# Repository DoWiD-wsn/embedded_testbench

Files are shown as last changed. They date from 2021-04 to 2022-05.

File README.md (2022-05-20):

# Embedded Testbench (ETB)

The **E**mbedded **T**est**b**ench (**ETB**) is a platform consisting of a Raspberry Pi add-on and a Python library designed to enable the testing, analyzing, and profiling of embedded systems.
A focus is laid on low-power embedded systems such as wireless sensor nodes.
Additionally, the ETB supports test automation with the possibility of remote control via TCP/IP.

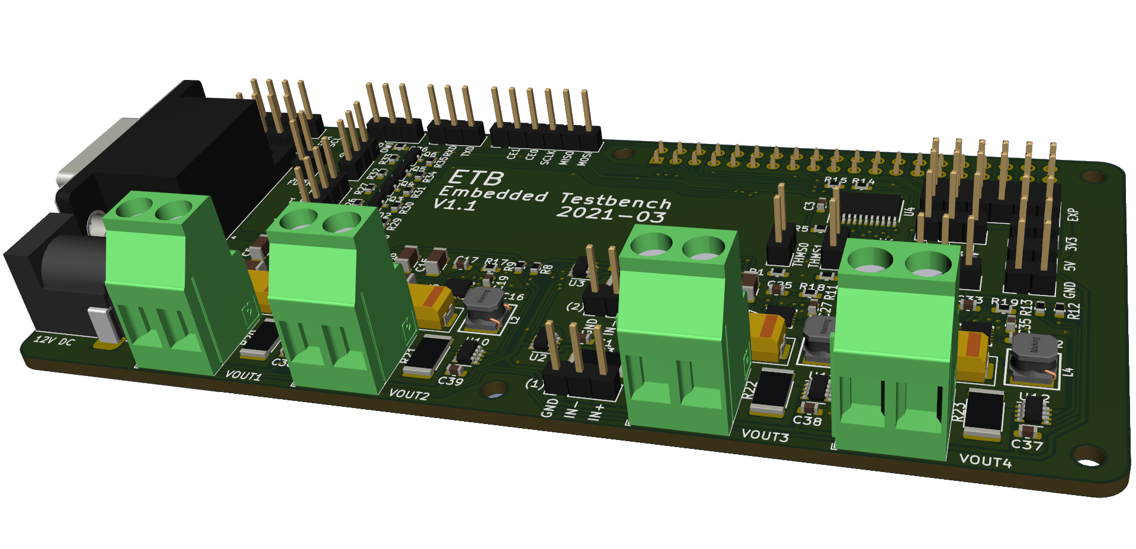
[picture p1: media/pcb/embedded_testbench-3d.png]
PCB 3D (/media/pcb/embedded_testbench-3d.png)


## Key Facts

* 40-pin expansion header for Raspberry Pi [2|3|4] model B+
* 4 mounting holes matching the Raspberry Pi [2|3|4] model B+ layout
* Compact size of 122 x 56 mm
* 4 controllable voltage domains supplied via own 12V input  
    (0.64 to 5.25V, in 5|10|30|50 mV steps, with a current limit of 3A each; see [MIC24045 datasheet](docs/datasheets/mic24045.pdf))
* 6 wattmeter: one per voltage domain + 2 additional  
    (0 to 26V, +/- 3.2A (max), 1.5 mA resolution, 1% precision; see [INA219 datasheet](docs/datasheets/ina219.pdf))
* 4 channel 16-bit ADC: 2 general + 2 for thermistor (see [ADS1115 datasheet](docs/datasheets/ads1115.pdf))
* I2C multiplexer for easier channel selection (voltage supply + wattmeter; see [TCA9548A datasheet](docs/datasheets/tca9548a.pdf))
* 12-pin expansion header (2x PWM, 6x GPIO, +3V3/+5V, and 2x GND)
* 4 test control signals (reset, enable, running, result)
* Connectors for TWI (2x), OWI (1x), SPI (1x), and UART (1x)
* Connectors for UART (1x) and test control signals (1x)  
    (with MOSFET-based bi-directional level shifter for voltage domain #1)
* Connectors for +3V3, +5V, and GND 
* Dsub 15 HD connector for DUT (e.g., useful for climate chamber experiments)

## Contents

```
.
├── docs                : documents & project documentation
│   └── datasheets      : datasheets of components used
├── kicad               : KiCad files
├── media               : Miscellaneous media (images, etc.)
│   ├── pcb             : Photos and rendered images of the PCB
│   └── schematic       : SVG images of the schematics
└── source              : Python library and example scripts
```

For more information on the PCB (and its design) refer to [docs/pcb_design.md](docs/pcb_design.md).
The python library, its functionality, and usage as well as example scripts are presented in [docs/python_library.md](docs/python_library.md).

## Built with

* [KiCad EAD 5.1.9](https://kicad.org/) - PCB design
* [Python 3.7.3](https://www.python.org/) - Python library

## Contributors

* **Dominik Widhalm** - [***DC-RES***](https://informatics.tuwien.ac.at/doctoral/resilient-embedded-systems/) - [*UAS Technikum Wien*](https://embsys.technikum-wien.at/staff/widhalm/)

Contributions of any kind to improve the project are highly welcome.
For coding bugs or minor improvements simply use pull requests.
However, for major changes or general discussions please contact [Dominik Widhalm](mailto:widhalm@technikum-wien.at?subject=Embedded%20Testbench%20(ETB)%20on%20GitHub).

## Publications

The embedded testbench (ETB) has already been successfully utilized in the following publications:

- Dominik Widhalm, Karl M. Goeschka, and Wolfgang Kastner, "*An open-source wireless sensor node platform with active node-level reliability for monitoring applications*", Sensors 21, no. 22: 7613, 2021, DOI: [10.3390/s21227613](https://doi.org/10.3390/s21227613)
- Dominik Widhalm, Karl M. Goeschka, and Wolfgang Kastner, "*Undervolting on wireless sensor nodes: a critical perspective*", in The 23rd International Conference on Distributed Computing and Networking (ICDCN 2022), January 4-7, 2022, DOI: [10.1145/3491003.3491018](https://doi.org/10.1145/3491003.3491018)
- Dominik Widhalm, Karl M. Goeschka, and Wolfgang Kastner, "*Is Arduino a suitable platform for sensor nodes?*", in The 47th Annual Conference of the IEEE Industrial Electronics Society (IECON 2021), October 13-16, 2021, DOI: [10.1109/IECON48115.2021.9589479](https://doi.org/10.1109/IECON48115.2021.9589479)
- Dominik Widhalm, Karl M. Goeschka, and Wolfgang Kastner, "*Node-level indicators of soft faults in wireless sensor networks*", in The 40th International Symposium on Reliable Distributed Systems (SRDS 2021), September 20-23, 2021, DOI: [10.1109/SRDS53918.2021.00011](https://doi.org/10.1109/SRDS53918.2021.00011)

## Changelog

A list of prior versions and changes between the updates can be found inn the [CHANGELOG.md](CHANGELOG.md) file.
Note that the major and minor number refer to the hardware version of the ETB board while the patch version is used to denote subsequent software versions.

## License

This project is licensed under the MIT License - see the [LICENSE.md](LICENSE.md) file for details.

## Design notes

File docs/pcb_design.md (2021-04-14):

# ETB - PCB Design

The board was designed with KiCad `version 5.1.9` and mainly uses schematic symbols and PCB footprints available in the [KiCad libraries](https://kicad.org/libraries/download/).
Parts not included in these libraries are available as project-specific libraries (see below).
The design requires only a two-layer PCB with all components (except the Raspberry Pi header) placed on the top side.
Also, it has enough ground zone area to avoid heating or EMI issues.

## Contents

```
kicad/
├── components                      : hierarchical schematic components
│   ├── ina219.sch                  : INA219-based wattmeter
│   ├── mic24045.sch                : MIC24045-based DC/DC converter
│   ├── shifter_2.sch               : MOSFET-based bi-directional level shifter (2 channel)
│   └── shifter_4.sch               : MOSFET-based bi-directional level shifter (4 channel)
├── myfootprint.pretty              : custom PCB footprints
│   ├── FQFN33-20LD-PL-1.kicad_mod  : FQFN33 footprint for MIC24045
│   └── L_Bourns-SRN5040.kicad_mod  : Bourns SRN5040 inductor footprint
├── embedded_testbench.kicad_pcb    : PCB layout file
├── embedded_testbench.lib          : schematic symbols library file
├── embedded_testbench.ods          : BOM (created with LibreOffice Calc version 7.1.1.2)
├── embedded_testbench.pro          : KiCad project file
├── embedded_testbench.sch          : schematic layout file
├── fp-lib-table                    : project-specific footprint library list
├── mycomponents.dcm                : custom schematic library (descriptions, aliases and keywords)
├── mycomponents.lib                : custom schematic library
└── sym-lib-table                   : project-specific symbol library list
```

## Costs

For the bill of materials (BOM) provided in the `.ods` file links to suitable components available at [Farnell](https://www.farnell.com/) are given including the prices valid at the time of the development (2021-03).
The cost of one *ETB* was around 53€ for the components ([Farnell](https://www.farnell.com/)) and around 15€ for the PCB ([PCB Pool / Beta Layout](https://eu.beta-layout.com/pcb/)).
Thus, the total costs of one *ETB* are below **70€**.
Depending on the supplier and quantities ordered, the costs may vary.

## Schematic

**Main schematic**:  
Main Schematic (/media/schematic/embedded_testbench-main.svg)

**Embedded hierarchical schematics**:  
* MIC24045 Schematic ([#1](../media/schematic/embedded_testbench-mic1.svg),[#2](../media/schematic/embedded_testbench-mic2.svg),[#3](../media/schematic/embedded_testbench-mic3.svg),[#4](../media/schematic/embedded_testbench-mic4.svg))  
* INA219 Schematic ([#1](../media/schematic/embedded_testbench-ina1.svg),[#2](../media/schematic/embedded_testbench-ina2.svg),[#3](../media/schematic/embedded_testbench-ina3.svg),[#4](../media/schematic/embedded_testbench-ina4.svg))  
* [CTRL shifter Schematic](../media/schematic/embedded_testbench-shifter_ctrl.svg)  
* [UART shifter Schematic](../media/schematic/embedded_testbench-shifter_uart.svg)  

## PCB Design

Front:  
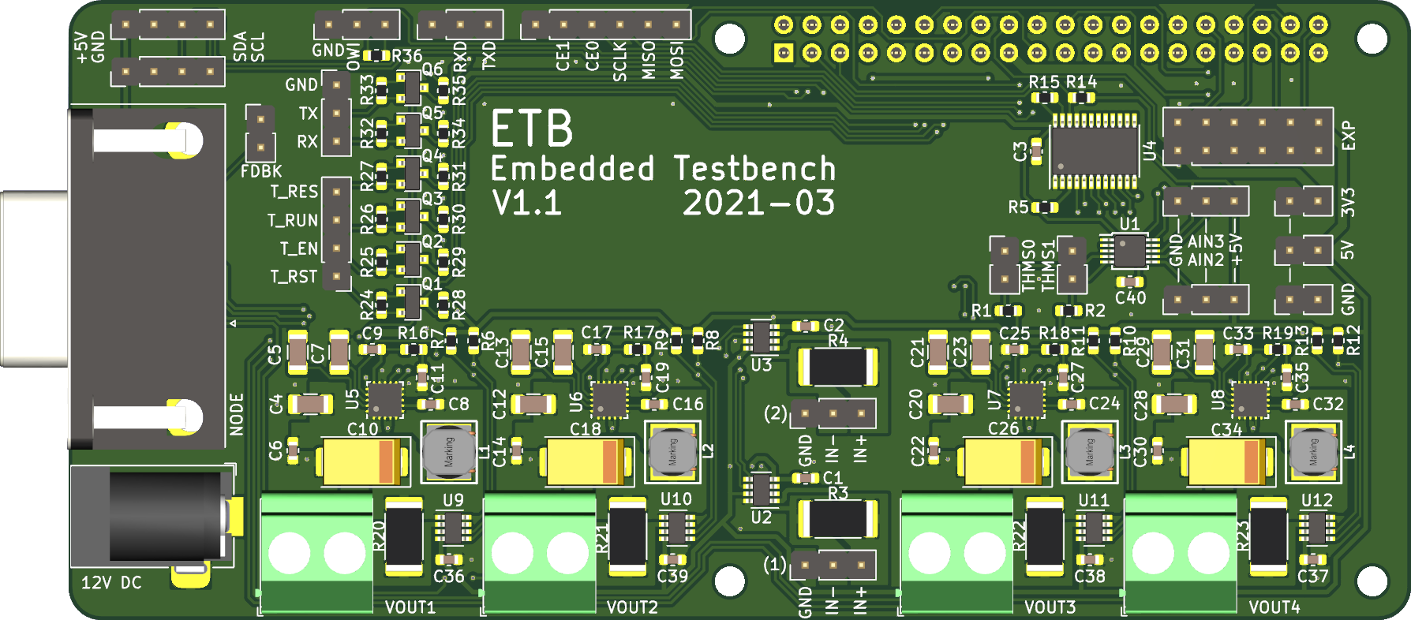
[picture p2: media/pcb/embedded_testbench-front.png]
PCB front (/media/pcb/embedded_testbench-front.png)


Back:  
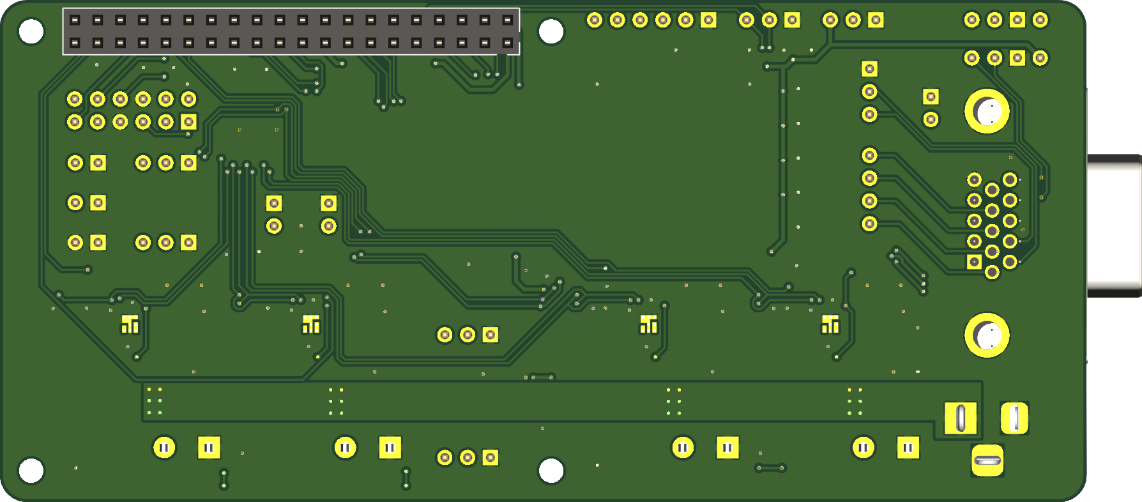
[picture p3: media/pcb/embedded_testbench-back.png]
PCB back (/media/pcb/embedded_testbench-back.png)


For the PCB design the following rules were used:
* Design rules:
    * Minimum track width: `0.15 mm`
    * Minimum via diameter: `0.6 mm`
    * Minimum via drill: `0.3 mm`
    * Minimum hole to hole: `0.25 mm`
    * `Prohibit overlapping courtyards`
* Tracks:
    * `0.2 mm`
    * `0.25 mm`
    * `0.4 mm`
    * `0.8 mm`
* Vias:
    * Size: `0.6 mm`
    * Drill: `0.3 mm`
* Zones:
    * Clearance: `0.3 mm`
    * Minimum width: `0.18 mm`
    * Pad connections: `Thermal reliefs`
    * Thermal clearance: `0.18 mm`
    * Thermal spoke width: `0.8 mm`

## Components and Libraries

An interactive BOM can be found in the `/kicad/bom/` directory (see [here](../kicad/bom/embedded_testbench.html); created with [InteractiveHtmlBom](https://github.com/openscopeproject/InteractiveHtmlBom)).

| Reference | Value | Symbol Library | Symbol | Footprint Library | Footprint |
|---|---|---|---|---|---|
| C9,C17,C25,C33 | 47pF | Device | C | Capacitor_SMD | C_0603_1608Metric |
| C11,C19,C27,C35 | 10nF | Device | C | Capacitor_SMD | C_0603_1608Metric |
| C1-C3,C6,C8,C14,C16,C22,C24,C30,C32,C36-C40 | 100nF | Device | C | Capacitor_SMD | C_0603_1608Metric |
| C5,C7,C13,C15,C21,C23,C29,C31 | 2.2uF | Device | C | Capacitor_SMD | C_1206_3216Metric |
| C4,C12,C20,C28 | 22uF | Device | C | Capacitor_SMD | C_1206_3216Metric |
| C10,C18,C26,C34 | 100uF | Device | CP1 | Capacitor_Tantalum_SMD | CP_EIA-7343-31_Kemet-D |
| L1-L4 | 2.2uH | Device | L | *myfootprint*`*` | L_Bourns-SRN5040 |
| R3,R4,R20-R23 | 0.1ohm | Device | R | Resistor_SMD | R_2512_6332Metric |
| R16-R19 | 2.7kohm | Device | R | Resistor_SMD | R_0603_1608Metric |
| R1,R2,R5-R15,R24-R36 | 10kohm | Device | R | Resistor_SMD | R_0603_1608Metric |
| Q1-Q6 | BSS138 | Transistor_FET | BSS138 | Package_TO_SOT_SMD | SOT-23 |
| U1 | ADS1115IDGS | Analog_ADC | DS1115IDGS | Package_SO | TSSOP-10_3x3mm_P0.5mm |
| U2,U3,U9-U12 | INA219 | *mycomponents*`*` | INA219 | Package_TO_SOT_SMD | SOT-23-8 |
| U4 | TCA9548APW | Interface_Expansion | TCA9548APWR | Package_SO | TSSOP-24_4.4x7.8mm_P0.65mm |
| U5-U8 | MIC24045 | *mycomponents*`*` | MIC24045 | *myfootprint*`*` | FQFN33-20LD-PL-1 |
| J1 | - | Connector | Barrel_Jack_Switch | Connector_BarrelJack | BarrelJack_Horizontal |
| J4,J7,J8,J10 | - | Connector_Generic | Conn_01x02 | TerminalBlock_Philmore | TerminalBlock_Philmore_TB132_1x02_P5.00mm_Horizontal |
| J2-J3,J13-J15,J22 | - | Connector_Generic | Conn_01x02 | Connector_PinHeader_2.54mm | PinHeader_1x02_P2.54mm_Vertical |
| J5,J9,J11,J16-J19 | - | Connector_Generic | Conn_01x03 | Connector_PinHeader_2.54mm | PinHeader_1x03_P2.54mm_Vertical |
| J6,J20-J21 | - | Connector_Generic | Conn_01x04 | Connector_PinHeader_2.54mm | PinHeader_1x04_P2.54mm_Vertical |
| J12 | - | Connector_Generic | Conn_01x06 | Connector_PinHeader_2.54mm | PinHeader_1x06_P2.54mm_Vertical |
| J23 | - | Connector_Generic | Conn_02x06_Counter_Clockwise | Connector_PinHeader_2.54mm | PinHeader_2x06_P2.54mm_Vertical |
| P1 | - | Connector_Generic | Conn_02x20_Odd_Even | Connector_PinHeader_2.54mm | PinHeader_2x20_P2.54mm_Vertical |
| J24 | - | Connector | DB15_Female_HighDensity_MountingHoles | Connector_Dsub | DSUB-15-HD_Female_Horizontal_P2.29x1.98mm_EdgePinOffset8.35mm_Housed_MountingHolesOffset10.89mm |
| MK1-MK4 | - | Mechanical | MountingHole | MountingHole | MountingHole_2.7mm_M2.5 |

If your installation of KiCad is missing (some of) the standard libraries, you can download them from [KiCad libraries](https://kicad.org/libraries/download/).
The custom libraries required (marked with `*`) are all contained in this repository.

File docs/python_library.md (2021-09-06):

# ETB - Python Library

One strength of the *ETB* is its rich and easily accessible set of functionalities.
While the hardware modules could also be controlled by other languages, we decided to use Python (specifically Python 3) for our purposes due to its widespread use and the availability of supportive libraries.
In the following, the preparation of the Raspberry Pi (in the following shortly named *RPi*), the installation of the required packages, and the use of the *ETB* library are presented.
However, you can access the RPi either locally if you have the graphical desktop environment installed, or remotely via [SSH](https://www.raspberrypi.org/documentation/remote-access/ssh/unix.md).
For the latter, make sure you have the SSH server enabled (see [here](https://www.raspberrypi.org/documentation/remote-access/ssh/)).

The *ETB* library provides:
* control over operational parameters such as supply voltage (and ambient temperature; see below)
* collection of DUT responses
* data storage (database or [CSV](https://docs.python.org/3/library/csv.html))
* data analysis (using [numpy](https://numpy.org/) and [scipy](https://www.scipy.org/))
* data visualization (using [matplotlib](https://matplotlib.org/))

For the future, also a web interface to facilitate the (remote) access even further is planned.

---
## Content

1. [Raspberry Pi Preparation](#raspberry-pi-preparation)
    * [Activate OWI Interface](#activate-owi-interface)
    * [Activate TWI Interface](#activate-twi-interface)
    * [Activate UART interface](#activate-uart-interface)
2. [Python Dependencies](#python-dependencies)
3. [Additional Software](#additional-software)
    * [Database Server](#database-server)
        * [Install MariaDB](#install-mariadb)
        * [Install PhpMyAdmin](#install-phpmyadmin)
        * [Prepare Databases](#prepare-databases)
    * [DHCP Server on LAN](#dhcp-server-on-lan)
4. [ETB Library Usage](#etb-library-usage)

---

## Raspberry Pi Preparation

The RPi provides hardware support for several communication interfaces.
In our case, we use the one-wire interface (OWI) for the DS18B20 temperature sensor, the two-wire interface (TWI) for the ADC, the DC/DC converter, and the wattmeter as well as the universal asynchronous receiver-transmitter (UART) to directly communicate with the DUT.
The setup of these interfaces on the RPi is described below.

### Activate OWI Interface

Follow these steps to enable the one-wire interface (OWI), see also [here](https://www.circuitbasics.com/raspberry-pi-ds18b20-temperature-sensor-tutorial/):
* To activate the required [DT overlay (DTO)](https://www.raspberrypi.org/documentation/configuration/device-tree.md), enter  
    `sudo nano /boot/config.txt`  
    and add this to the bottom of the file:  
    `dtoverlay=w1-gpio`
* Save and exit the editor; then reboot the Pi, e.g. with `sudo reboot`
* Log in to the RPi again and at the command prompt enter:  
    `sudo modprobe wire`  
    `sudo modprobe w1-gpio`  
    `sudo modprobe w1-therm`
* You can check whether the modules are loaded with:  
    `sudo lsmod`

To enable access to the DS18B20 temperature sensor:
* Change the working directory to `/sys/bus/w1/devices` by entering:  
    `cd /sys/bus/w1/devices`
* Now enter `ls` to list the devices.  
    For example, `28-011927fdb603 w1_bus_master1` will be displayed.
* Now enter `cd 28-011927fdb603`  
    (or whatever address the sensor has on your system)
* Enter `cat w1_slave` which will show the raw temperature reading output by the sensor, where the temperature reading is `t=28625`, which means a temperature of 28.625 degrees Celsius.
* You will need to check and adjust the sensor's serial (e.g., 28-xxx) in the Python scripts (will be explained later).

### Activate TWI interface

Follow these steps to enable the two-wire interface (TWI), respectively the inter-integrated circuit (I2C) interface (see also [here](https://learn.adafruit.com/adafruit-stemma-soil-sensor-i2c-capacitive-moisture-sensor/python-circuitpython-test)):
* Log in to the RPi and enter:  
    `sudo raspi-config`
    * Under `Interfacing Options` select `P5 I2C`
    * Confirm enabling the I2C module
* To check if an I2C device is available, enter:  
    `sudo i2cdetect -y 1`  
    You will see at which address devices are available (e.g., `48` for the ADS1115 ADC)

### Activate UART interface

Follow these steps to enable the UART interface (see also [here](https://www.electronicwings.com/raspberry-pi/raspberry-pi-uart-communication-using-python-and-c), [here](https://www.raspberrypi.org/documentation/configuration/uart.md) and [here](https://buyzero.de/blogs/news/praktische-kommunikation-per-uart-und-rs485-am-raspberry-pi):
* Log in to the RPi and execute:  
    `sudo raspi-config`
    * Under `Interfacing Options` select `P6 Serial`
    * Confirm disabling the serial access to the login shell
    * Confirm enabling the serial port hardware
* For the RPi 3|4, we have to deactivate the Bluetooth (BT) interface (which uses the serial interface by default):  
    `sudo systemctl disable hciuart`
* Last but not least, we need to select the right [DTO](https://www.raspberrypi.org/documentation/configuration/device-tree.md):  
    `sudo nano /boot/config.txt`  
    Add at the end (there should be `enable_uart=1` now):  
    `dtoverlay=pi3-disable-bt`
* After that, the RPi needs to be rebooted:  
    `sudo reboot`

---

## Python Dependencies

Dependency graph:
PCB front (/media/python/dependency_graph.svg)

The test node runs python scripts and uses the raspberry's GPIOs, the one-wire interface, and the two-wire interface (I2C).
For this purpose the following libraries are needed:

* Python 3:  
    `sudo apt install python3-pip python3-dev`  
* I2C:  
    `sudo apt install i2c-tools python3-smbus`
* MySQL:  
    `sudo apt install default-libmysqlclient-dev`  
    `python3 -m pip install mysql-connector-python`
* Zigbee:  
    `python3 -m pip install digi-xbee`
* Matplotlib:  
    `sudo apt install python3-tk libatlas-base-dev libopenjp2-7-dev`  
    `python3 -m pip install matplotlib numpy scipy`

---

## Additional Software

### Database Server

#### Install MariaDB

The installation mainly follows the guide provided [here](https://pimylifeup.com/raspberry-pi-mysql/).
* Update our package list:  
  `sudo apt update`
* Install the MariaDB (MySQL) server package:  
  `sudo apt install mariadb-server`
* Secure the installation:  
  `sudo mysql_secure_installation`
    * Set the root password:  
      `$passWD$`
* Test the access:  
  `sudo mysql -u root -p`

#### Install PhpMyAdmin

* Install <a href="https://www.phpmyadmin.net/" target="_blank">`phpMyAdmin`</a>:  
  `sudo apt install phpmyadmin`
    * During the installation, <a href="https://www.phpmyadmin.net/" target="_blank">`phpMyAdmin`</a> will walk you through a basic configuration:
        * Select `Apache2` for the server
        * Choose `YES` when asked about whether to Configure the database for phpmyadmin with `dbconfig-common`
        * Enter your `MySQL` password when prompted:  
          `$passWD$`
        * Enter the password that you want to use to log into phpMyAdmin:  
          `$passWD$`
* Finish Installation:
  In MySQL 5.7 (released Oct 2015) and MySQL 8, the root MySQL user is set to authenticate using the auth_socket or caching_sha2_password plugin rather than with mysql_native_password. This will prevent programs like phpMyAdmin from logging in with the root account.
    * Enable remote `mysql` access:  
      `sudo nano /etc/mysql/mariadb.conf.d/50-server.cnf`
        * Comment the line with:  
          `#bind-address=127.0.0.1`
        * Save config file (`CTRL+O` and `CTRL+X`)
    * Create a New Superuser for phpMyAdmin:
        * Open up the MySQL prompt from your terminal:  
          `sudo mysql -p -u root`
        * Create a new superuser (with local access only):  
          `CREATE USER 'admin'@'localhost' IDENTIFIED BY '$passWD$';`  
          `GRANT ALL PRIVILEGES ON *.* TO 'admin'@'localhost' WITH GRANT OPTION;`  
          `FLUSH PRIVILEGES;`
    * Restart the `mysql` service:  
      `sudo /etc/init.d/mysql restart`
    * Now <a href="http://10.0.0.43/phpmyadmin/" target="_blank">`phpMyAdmin`</a> is available on your system.
        * You can access phpmyadmin with the user `admin` and the previously set password.
* Additional Apache configuration:
    * Additionally PHP should be provided:  
      `sudo apt install php php-mcrypt php-mysql`
    * Apache is running as user *www-data*, so make this user owner of html directory  
      `sudo chown -R www-data:www-data /var/www/html`
    * Add user *pi* to this group:  
      `sudo usermod -a -G www-data pi`
    * Change html directory rights to enable write access for user `pi`:  
      `sudo chmod 775 /var/www/html/`
* Fix bugs in PHPMyAdmin:
    * Open the SQL.lib file:  
      `sudo nano /usr/share/phpmyadmin/libraries/sql.lib.php`
        * Replace the line:  
          ``((empty($analyzed_sql_results['select_expr']))``  
          ``    || (count($analyzed_sql_results['select_expr'] == 1)``  
          ``        && ($analyzed_sql_results['select_expr'][0] == '*')))``  
          with:  
          ``((empty($analyzed_sql_results['select_expr']))``  
          ``    || (count($analyzed_sql_results['select_expr']) == 1)``  
          ``        && ($analyzed_sql_results['select_expr'][0] == '*'))``
        * See also [here](https://devanswers.co/problem-php-7-2-phpmyadmin-warning-in-librariessql-count/)

#### Prepare Databases

For the WSN testbed setup, we will use an own user for the DB access.

* Start MySQL:  
  `sudo mysql -u root -p`
  * Enter previously set password  
* Create an own user for the WSN testbed:
  `CREATE USER 'mywsn' IDENTIFIED BY '$passWD$';`
* Set the respective access rights:  
  ``GRANT ALL ON `experiments`.* TO 'mywsn'@'%';``  
  `FLUSH PRIVILEGES;`
* Exit MySQL:  
  `quit`

Further configuration and setup of the databases are done via `PHPmyAdmin`.

### DHCP Server on LAN

Since some equipment like the climate chamber is connected via Ethernet, we need to activate the DHCP server on the raspberry.

* Install the `ISC DHCP server` (will initially fail, see below):  
  `sudo apt install isc-dhcp-server`
* Select which interfaces shall use DHCP:  
  `sudo nano /etc/default/isc-dhcp-server`
    * Add `eth0` to the IPv4 interfaces:  
      `INTERFACESv4="eth0"`
* Several parameters must be activated and configured:  
  `sudo nano /etc/dhcp/dhcpd.conf`
    * Besides the configuration template, the following lines are all we need:
```
option domain-name "raspberry.local";
option domain-name-servers 8.8.8.8, 4.4.4.4;

default-lease-time 600;
max-lease-time 7200;

# authoritative; # Is handled in the subnet definition

subnet 192.168.0.0 netmask 255.255.255.0 {
  authoritative;
  range 192.168.0.2 192.168.0.50;
  option subnet-mask 255.255.255.0;
  option routers 192.168.0.1;
  option broadcast-address 192.168.0.255;
}
```
* To configure the network interfaces, create a local config with:  
  `sudo nano /etc/network/interfaces.d/locals`
    * We want to activate the DHCP server on the `eth0` interface:
```
auto lo
iface lo inet loopback

#auto wlan0
allow-hotplug wlan0
iface wlan0 inet dhcp
  wpa-conf /etc/wpa_supplicant/wpa_supplicant.conf

allow-hotplug eth0
iface eth0 inet static
  address 192.168.0.1
  netmask 255.255.255.0
```
* Now, bring eth0 down and up again:  
  `sudo ifdown eth0` (may fail if its not up)  
  `sudo ifup eth0`
* Start the DHCP server:  
  `sudo service isc-dhcp-server start`
* Check the status of the DHCP server:  
  `sudo systemctl status isc-dhcp-server.service`
* If we want to assign a static IP address to a device, we can add a block in the configuration:  
  `sudo nano /etc/dhcp/dhcpd.conf`
    * Assume our device `climatechamber` has the MAC address `00:11:22:33:44:55`, then simply add the following lines to the subnet block:
```
    host climatechamber {
        hardware ethernet 00:11:22:33:44:55;
        fixed-address 192.168.0.4;
    }
```

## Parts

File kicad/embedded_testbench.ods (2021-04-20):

Reference | Value | Footprint | Dist. | Price | Note
C1 | 100n | Capacitor_SMD:C_0603_1608Metric | [Farnell] (https://at.farnell.com/kemet/c0603c104m5ractu/kondensator-0-1-f-50v-20-x7r-0603/dp/2581046) | € 0,019 | Min. 10 pcs.
C10 | 100u | Capacitor_Tantalum_SMD:CP_EIA-7343-31_Kemet-D | [Farnell] (https://at.farnell.com/avx/tajd107k016snj/kondensator-100-f-16v-10/dp/2852741) | € 0,750 | Min. 5 pcs.
C11 | 10n | Capacitor_SMD:C_0603_1608Metric | [Farnell] (https://at.farnell.com/kemet/c0603c103m5ractu/kondensator-0-01-f-50v-20-x7r/dp/2581043) | € 0,023 | Min. 10 pcs.
C12 | 22u | Capacitor_SMD:C_1206_3216Metric | [Farnell] (https://at.farnell.com/kemet/c1206c226m8ractu/kondensator-22-f-10v-20-x7r-1206/dp/2118135) | € 0,438 | Min. 5 pcs.
C13 | 2.2u | Capacitor_SMD:C_1206_3216Metric | [Farnell] (https://at.farnell.com/murata/gcm31cr71h225ka55l/kondensator-2-2-f-50v-10-x7r-1206/dp/2470443) | € 0,186 | Min. 10 pcs.
C14 | 100n | Capacitor_SMD:C_0603_1608Metric | [Farnell] (https://at.farnell.com/kemet/c0603c104m5ractu/kondensator-0-1-f-50v-20-x7r-0603/dp/2581046) | € 0,019 | Min. 10 pcs.
C15 | 2.2u | Capacitor_SMD:C_1206_3216Metric | [Farnell] (https://at.farnell.com/murata/gcm31cr71h225ka55l/kondensator-2-2-f-50v-10-x7r-1206/dp/2470443) | € 0,186 | Min. 10 pcs.
C16 | 100n | Capacitor_SMD:C_0603_1608Metric | [Farnell] (https://at.farnell.com/kemet/c0603c104m5ractu/kondensator-0-1-f-50v-20-x7r-0603/dp/2581046) | € 0,019 | Min. 10 pcs.
C17 | 47p | Capacitor_SMD:C_0603_1608Metric | [Farnell] (https://at.farnell.com/kemet/c0603c470k5ractu/kondensator-47pf-50v-10-x7r-0603/dp/2819765) | € 0,111 | Min. 10 pcs.
C18 | 100u | Capacitor_Tantalum_SMD:CP_EIA-7343-31_Kemet-D | [Farnell] (https://at.farnell.com/avx/tajd107k016snj/kondensator-100-f-16v-10/dp/2852741) | € 0,750 | Min. 5 pcs.
C19 | 10n | Capacitor_SMD:C_0603_1608Metric | [Farnell] (https://at.farnell.com/kemet/c0603c103m5ractu/kondensator-0-01-f-50v-20-x7r/dp/2581043) | € 0,023 | Min. 10 pcs.
C2 | 100n | Capacitor_SMD:C_0603_1608Metric | [Farnell] (https://at.farnell.com/kemet/c0603c104m5ractu/kondensator-0-1-f-50v-20-x7r-0603/dp/2581046) | € 0,019 | Min. 10 pcs.
C20 | 22u | Capacitor_SMD:C_1206_3216Metric | [Farnell] (https://at.farnell.com/kemet/c1206c226m8ractu/kondensator-22-f-10v-20-x7r-1206/dp/2118135) | € 0,438 | Min. 5 pcs.
C21 | 2.2u | Capacitor_SMD:C_1206_3216Metric | [Farnell] (https://at.farnell.com/murata/gcm31cr71h225ka55l/kondensator-2-2-f-50v-10-x7r-1206/dp/2470443) | € 0,186 | Min. 10 pcs.
C22 | 100n | Capacitor_SMD:C_0603_1608Metric | [Farnell] (https://at.farnell.com/kemet/c0603c104m5ractu/kondensator-0-1-f-50v-20-x7r-0603/dp/2581046) | € 0,019 | Min. 10 pcs.
C23 | 2.2u | Capacitor_SMD:C_1206_3216Metric | [Farnell] (https://at.farnell.com/murata/gcm31cr71h225ka55l/kondensator-2-2-f-50v-10-x7r-1206/dp/2470443) | € 0,186 | Min. 10 pcs.
C24 | 100n | Capacitor_SMD:C_0603_1608Metric | [Farnell] (https://at.farnell.com/kemet/c0603c104m5ractu/kondensator-0-1-f-50v-20-x7r-0603/dp/2581046) | € 0,019 | Min. 10 pcs.
C25 | 47p | Capacitor_SMD:C_0603_1608Metric | [Farnell] (https://at.farnell.com/kemet/c0603c470k5ractu/kondensator-47pf-50v-10-x7r-0603/dp/2819765) | € 0,111 | Min. 10 pcs.
C26 | 100u | Capacitor_Tantalum_SMD:CP_EIA-7343-31_Kemet-D | [Farnell] (https://at.farnell.com/avx/tajd107k016snj/kondensator-100-f-16v-10/dp/2852741) | € 0,750 | Min. 5 pcs.
C27 | 10n | Capacitor_SMD:C_0603_1608Metric | [Farnell] (https://at.farnell.com/kemet/c0603c103m5ractu/kondensator-0-01-f-50v-20-x7r/dp/2581043) | € 0,023 | Min. 10 pcs.
C28 | 22u | Capacitor_SMD:C_1206_3216Metric | [Farnell] (https://at.farnell.com/kemet/c1206c226m8ractu/kondensator-22-f-10v-20-x7r-1206/dp/2118135) | € 0,438 | Min. 5 pcs.
C29 | 2.2u | Capacitor_SMD:C_1206_3216Metric | [Farnell] (https://at.farnell.com/murata/gcm31cr71h225ka55l/kondensator-2-2-f-50v-10-x7r-1206/dp/2470443) | € 0,186 | Min. 10 pcs.
C3 | 100n | Capacitor_SMD:C_0603_1608Metric | [Farnell] (https://at.farnell.com/kemet/c0603c104m5ractu/kondensator-0-1-f-50v-20-x7r-0603/dp/2581046) | € 0,019 | Min. 10 pcs.
C30 | 100n | Capacitor_SMD:C_0603_1608Metric | [Farnell] (https://at.farnell.com/kemet/c0603c104m5ractu/kondensator-0-1-f-50v-20-x7r-0603/dp/2581046) | € 0,019 | Min. 10 pcs.
C31 | 2.2u | Capacitor_SMD:C_1206_3216Metric | [Farnell] (https://at.farnell.com/murata/gcm31cr71h225ka55l/kondensator-2-2-f-50v-10-x7r-1206/dp/2470443) | € 0,186 | Min. 10 pcs.
C32 | 100n | Capacitor_SMD:C_0603_1608Metric | [Farnell] (https://at.farnell.com/kemet/c0603c104m5ractu/kondensator-0-1-f-50v-20-x7r-0603/dp/2581046) | € 0,019 | Min. 10 pcs.
C33 | 47p | Capacitor_SMD:C_0603_1608Metric | [Farnell] (https://at.farnell.com/kemet/c0603c470k5ractu/kondensator-47pf-50v-10-x7r-0603/dp/2819765) | € 0,111 | Min. 10 pcs.
C34 | 100u | Capacitor_Tantalum_SMD:CP_EIA-7343-31_Kemet-D | [Farnell] (https://at.farnell.com/avx/tajd107k016snj/kondensator-100-f-16v-10/dp/2852741) | € 0,750 | Min. 5 pcs.
C35 | 10n | Capacitor_SMD:C_0603_1608Metric | [Farnell] (https://at.farnell.com/kemet/c0603c103m5ractu/kondensator-0-01-f-50v-20-x7r/dp/2581043) | € 0,023 | Min. 10 pcs.
C36 | 100n | Capacitor_SMD:C_0603_1608Metric | [Farnell] (https://at.farnell.com/kemet/c0603c104m5ractu/kondensator-0-1-f-50v-20-x7r-0603/dp/2581046) | € 0,019 | Min. 10 pcs.
C37 | 100n | Capacitor_SMD:C_0603_1608Metric | [Farnell] (https://at.farnell.com/kemet/c0603c104m5ractu/kondensator-0-1-f-50v-20-x7r-0603/dp/2581046) | € 0,019 | Min. 10 pcs.
C38 | 100n | Capacitor_SMD:C_0603_1608Metric | [Farnell] (https://at.farnell.com/kemet/c0603c104m5ractu/kondensator-0-1-f-50v-20-x7r-0603/dp/2581046) | € 0,019 | Min. 10 pcs.
C39 | 100n | Capacitor_SMD:C_0603_1608Metric | [Farnell] (https://at.farnell.com/kemet/c0603c104m5ractu/kondensator-0-1-f-50v-20-x7r-0603/dp/2581046) | € 0,019 | Min. 10 pcs.
C4 | 22u | Capacitor_SMD:C_1206_3216Metric | [Farnell] (https://at.farnell.com/kemet/c1206c226m8ractu/kondensator-22-f-10v-20-x7r-1206/dp/2118135) | € 0,438 | Min. 5 pcs.
C40 | 100n | Capacitor_SMD:C_0603_1608Metric | [Farnell] (https://at.farnell.com/kemet/c0603c104m5ractu/kondensator-0-1-f-50v-20-x7r-0603/dp/2581046) | € 0,019 | Min. 10 pcs.
C5 | 2.2u | Capacitor_SMD:C_1206_3216Metric | [Farnell] (https://at.farnell.com/murata/gcm31cr71h225ka55l/kondensator-2-2-f-50v-10-x7r-1206/dp/2470443) | € 0,186 | Min. 10 pcs.
C6 | 100n | Capacitor_SMD:C_0603_1608Metric | [Farnell] (https://at.farnell.com/kemet/c0603c104m5ractu/kondensator-0-1-f-50v-20-x7r-0603/dp/2581046) | € 0,019 | Min. 10 pcs.
C7 | 2.2u | Capacitor_SMD:C_1206_3216Metric | [Farnell] (https://at.farnell.com/murata/gcm31cr71h225ka55l/kondensator-2-2-f-50v-10-x7r-1206/dp/2470443) | € 0,186 | Min. 10 pcs.
C8 | 100n | Capacitor_SMD:C_0603_1608Metric | [Farnell] (https://at.farnell.com/kemet/c0603c104m5ractu/kondensator-0-1-f-50v-20-x7r-0603/dp/2581046) | € 0,019 | Min. 10 pcs.
C9 | 47p | Capacitor_SMD:C_0603_1608Metric | [Farnell] (https://at.farnell.com/kemet/c0603c470k5ractu/kondensator-47pf-50v-10-x7r-0603/dp/2819765) | € 0,111 | Min. 10 pcs.
J1 | 12V INPUT | Connector_BarrelJack:BarrelJack_Horizontal | [Farnell] (https://at.farnell.com/multicomp/mj-179ph/niederspannungsbuchse-12vdc-4a/dp/1737246) | € 0,854 | Min. 5 pcs.
J10 | VOUT4 | TerminalBlock_Philmore:TerminalBlock_Philmore_TB132_1x02_P5.00mm_Horizontal | [Farnell] (https://at.farnell.com/camdenboss/ctb0700-2/terminalblock-pcb-2kont-5mm/dp/1717084) | € 1,530 | Min. 100 pcs.
J11 | PM2 | Connector_PinHeader_2.54mm:PinHeader_1x03_P2.54mm_Vertical | [Farnell] (https://at.farnell.com/wurth-elektronik/61304011121/stiftleiste-2-54mm-tht-vertikal/dp/2356175?st=stiftleiste) | € 0,095 | 40 pins (50 needed → 2 pcs.)
J12 | SPI | Connector_PinHeader_2.54mm:PinHeader_1x06_P2.54mm_Vertical | [Farnell] (https://at.farnell.com/wurth-elektronik/61304011121/stiftleiste-2-54mm-tht-vertikal/dp/2356175?st=stiftleiste) | € 0,189 | 40 pins (50 needed → 2 pcs.)
J13 | 5V | Connector_PinHeader_2.54mm:PinHeader_1x02_P2.54mm_Vertical | [Farnell] (https://at.farnell.com/wurth-elektronik/61304011121/stiftleiste-2-54mm-tht-vertikal/dp/2356175?st=stiftleiste) | € 0,063 | 40 pins (50 needed → 2 pcs.)
J14 | 3V3 | Connector_PinHeader_2.54mm:PinHeader_1x02_P2.54mm_Vertical | [Farnell] (https://at.farnell.com/wurth-elektronik/61304011121/stiftleiste-2-54mm-tht-vertikal/dp/2356175?st=stiftleiste) | € 0,063 | 40 pins (50 needed → 2 pcs.)
J15 | GND | Connector_PinHeader_2.54mm:PinHeader_1x02_P2.54mm_Vertical | [Farnell] (https://at.farnell.com/wurth-elektronik/61304011121/stiftleiste-2-54mm-tht-vertikal/dp/2356175?st=stiftleiste) | € 0,063 | 40 pins (50 needed → 2 pcs.)
J16 | UART | Connector_PinHeader_2.54mm:PinHeader_1x03_P2.54mm_Vertical | [Farnell] (https://at.farnell.com/wurth-elektronik/61304011121/stiftleiste-2-54mm-tht-vertikal/dp/2356175?st=stiftleiste) | € 0,095 | 40 pins (50 needed → 2 pcs.)
J17 | OWI | Connector_PinHeader_2.54mm:PinHeader_1x03_P2.54mm_Vertical | [Farnell] (https://at.farnell.com/wurth-elektronik/61304011121/stiftleiste-2-54mm-tht-vertikal/dp/2356175?st=stiftleiste) | € 0,095 | 40 pins (50 needed → 2 pcs.)
J18 | AIN2 | Connector_PinHeader_2.54mm:PinHeader_1x03_P2.54mm_Vertical | [Farnell] (https://at.farnell.com/wurth-elektronik/61304011121/stiftleiste-2-54mm-tht-vertikal/dp/2356175?st=stiftleiste) | € 0,095 | 40 pins (50 needed → 2 pcs.)
J19 | AIN3 | Connector_PinHeader_2.54mm:PinHeader_1x03_P2.54mm_Vertical | [Farnell] (https://at.farnell.com/wurth-elektronik/61304011121/stiftleiste-2-54mm-tht-vertikal/dp/2356175?st=stiftleiste) | € 0,095 | 40 pins (50 needed → 2 pcs.)
J2 | THMS1 | Connector_PinHeader_2.54mm:PinHeader_1x02_P2.54mm_Vertical | [Farnell] (https://at.farnell.com/wurth-elektronik/61304011121/stiftleiste-2-54mm-tht-vertikal/dp/2356175?st=stiftleiste) | € 0,063 | 40 pins (50 needed → 2 pcs.)
J20 | TWI1 | Connector_PinHeader_2.54mm:PinHeader_1x04_P2.54mm_Vertical | [Farnell] (https://at.farnell.com/wurth-elektronik/61304011121/stiftleiste-2-54mm-tht-vertikal/dp/2356175?st=stiftleiste) | € 0,095 | 40 pins (50 needed → 2 pcs.)
J21 | TWI2 | Connector_PinHeader_2.54mm:PinHeader_1x04_P2.54mm_Vertical | [Farnell] (https://at.farnell.com/wurth-elektronik/61304011121/stiftleiste-2-54mm-tht-vertikal/dp/2356175?st=stiftleiste) | € 0,095 | 40 pins (50 needed → 2 pcs.)
J22 | FDBK | Connector_PinHeader_2.54mm:PinHeader_1x02_P2.54mm_Vertical | [Farnell] (https://at.farnell.com/wurth-elektronik/61304011121/stiftleiste-2-54mm-tht-vertikal/dp/2356175?st=stiftleiste) | € 0,063 | 40 pins (50 needed → 2 pcs.)
J23 | EXP | Connector_PinHeader_2.54mm:PinHeader_2x06_P2.54mm_Vertical | [Farnell] (https://at.farnell.com/amp-te-connectivity/1-825440-0/stiftleiste-2reihig-20pol/dp/3417827?st=stiftleiste) | € 2,300 | 20 pins (12 needed)
J24 | WSN_NODE | Connector_Dsub:DSUB-15-HD_Female_Horizontal_P2.29x1.98mm_EdgePinOffset8.35mm_Housed_MountingHolesOffset10.89mm | [Farnell] (https://at.farnell.com/amphenol/l77hde15sd1ch4r/hd-d-sub-buchse-15pos/dp/2401183?MER=sy-me-pd-mi-alte) | € 1,070 | -
J3 | THMS2 | Connector_PinHeader_2.54mm:PinHeader_1x02_P2.54mm_Vertical | [Farnell] (https://at.farnell.com/wurth-elektronik/61304011121/stiftleiste-2-54mm-tht-vertikal/dp/2356175?st=stiftleiste) | € 0,063 | 40 pins (50 needed → 2 pcs.)
J4 | VOUT1 | TerminalBlock_Philmore:TerminalBlock_Philmore_TB132_1x02_P5.00mm_Horizontal | [Farnell] (https://at.farnell.com/camdenboss/ctb0700-2/terminalblock-pcb-2kont-5mm/dp/1717084) | € 1,530 | Min. 100 pcs.
J5 | UARTS | Connector_PinHeader_2.54mm:PinHeader_1x03_P2.54mm_Vertical | [Farnell] (https://at.farnell.com/wurth-elektronik/61304011121/stiftleiste-2-54mm-tht-vertikal/dp/2356175?st=stiftleiste) | € 0,095 | 40 pins (50 needed → 2 pcs.)
J6 | CTRLS | Connector_PinHeader_2.54mm:PinHeader_1x04_P2.54mm_Vertical | [Farnell] (https://at.farnell.com/wurth-elektronik/61304011121/stiftleiste-2-54mm-tht-vertikal/dp/2356175?st=stiftleiste) | € 0,126 | 40 pins (50 needed → 2 pcs.)
J7 | VOUT2 | TerminalBlock_Philmore:TerminalBlock_Philmore_TB132_1x02_P5.00mm_Horizontal | [Farnell] (https://at.farnell.com/camdenboss/ctb0700-2/terminalblock-pcb-2kont-5mm/dp/1717084) | € 1,530 | Min. 100 pcs.
J8 | VOUT3 | TerminalBlock_Philmore:TerminalBlock_Philmore_TB132_1x02_P5.00mm_Horizontal | [Farnell] (https://at.farnell.com/camdenboss/ctb0700-2/terminalblock-pcb-2kont-5mm/dp/1717084) | € 1,530 | Min. 100 pcs.
J9 | PM1 | Connector_PinHeader_2.54mm:PinHeader_1x03_P2.54mm_Vertical | [Farnell] (https://at.farnell.com/wurth-elektronik/61304011121/stiftleiste-2-54mm-tht-vertikal/dp/2356175?st=stiftleiste) | € 0,095 | 40 pins (50 needed → 2 pcs.)
L1 | 2.2u | myfootprint:L_Bourns-SRN5040 | [Farnell] (https://at.farnell.com/murata/gcm31cr71h225ka55l/kondensator-2-2-f-50v-10-x7r-1206/dp/2470443) | € 0,186 | Min. 10 pcs.
L2 | 2.2u | myfootprint:L_Bourns-SRN5040 | [Farnell] (https://at.farnell.com/murata/gcm31cr71h225ka55l/kondensator-2-2-f-50v-10-x7r-1206/dp/2470443) | € 0,186 | Min. 10 pcs.
L3 | 2.2u | myfootprint:L_Bourns-SRN5040 | [Farnell] (https://at.farnell.com/murata/gcm31cr71h225ka55l/kondensator-2-2-f-50v-10-x7r-1206/dp/2470443) | € 0,186 | Min. 10 pcs.
L4 | 2.2u | myfootprint:L_Bourns-SRN5040 | [Farnell] (https://at.farnell.com/murata/gcm31cr71h225ka55l/kondensator-2-2-f-50v-10-x7r-1206/dp/2470443) | € 0,186 | Min. 10 pcs.
MK1 | M2.5 | MountingHole:MountingHole_2.7mm_M2.5 | - | € 0,000
MK2 | M2.5 | MountingHole:MountingHole_2.7mm_M2.5 | - | € 0,000
MK3 | M2.5 | MountingHole:MountingHole_2.7mm_M2.5 | - | € 0,000
MK4 | M2.5 | MountingHole:MountingHole_2.7mm_M2.5 | - | € 0,000
P1 | RPi Header | Connector_PinSocket_2.54mm:PinSocket_2x20_P2.54mm_Vertical | [Farnell] (https://at.farnell.com/harwin/m20-6112045/buchse-pc-104-40kont/dp/1569232) | € 3,750 | mount on bottom
Q1 | BSS138 | Package_TO_SOT_SMD:SOT-23 | [Farnell] (https://at.farnell.com/nexperia/bss138bk-215/mosfet-n-kanal-60v-0-36a-sot23/dp/2053833?st=bss138) | € 0,275 | -
Q2 | BSS138 | Package_TO_SOT_SMD:SOT-23 | [Farnell] (https://at.farnell.com/nexperia/bss138bk-215/mosfet-n-kanal-60v-0-36a-sot23/dp/2053833?st=bss138) | € 0,275 | -
Q3 | BSS138 | Package_TO_SOT_SMD:SOT-23 | [Farnell] (https://at.farnell.com/nexperia/bss138bk-215/mosfet-n-kanal-60v-0-36a-sot23/dp/2053833?st=bss138) | € 0,275 | -
Q4 | BSS138 | Package_TO_SOT_SMD:SOT-23 | [Farnell] (https://at.farnell.com/nexperia/bss138bk-215/mosfet-n-kanal-60v-0-36a-sot23/dp/2053833?st=bss138) | € 0,275 | -
Q5 | BSS138 | Package_TO_SOT_SMD:SOT-23 | [Farnell] (https://at.farnell.com/nexperia/bss138bk-215/mosfet-n-kanal-60v-0-36a-sot23/dp/2053833?st=bss138) | € 0,275 | -
Q6 | BSS138 | Package_TO_SOT_SMD:SOT-23 | [Farnell] (https://at.farnell.com/nexperia/bss138bk-215/mosfet-n-kanal-60v-0-36a-sot23/dp/2053833?st=bss138) | € 0,275 | -
R1 | 10k / 0.1% | Resistor_SMD:R_0603_1608Metric | [Farnell] (https://at.farnell.com/panasonic/era3aeb103v/metallsch-widerstand-10k-0-1-0/dp/1577619) | € 0,256 | Min. 10 pcs.
R10 | 10k | Resistor_SMD:R_0603_1608Metric | [Farnell] (https://at.farnell.com/yageo/ac0603fr-0710kl/dickschichtwiderstand-10k-1-0/dp/3495224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) | € 0,022 | Min. 10 pcs.
R11 | 10k | Resistor_SMD:R_0603_1608Metric | [Farnell] (https://at.farnell.com/yageo/ac0603fr-0710kl/dickschichtwiderstand-10k-1-0/dp/3495224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) | € 0,022 | Min. 10 pcs.
R12 | 10k | Resistor_SMD:R_0603_1608Metric | [Farnell] (https://at.farnell.com/yageo/ac0603fr-0710kl/dickschichtwiderstand-10k-1-0/dp/3495224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) | € 0,022 | Min. 10 pcs.
R13 | 10k | Resistor_SMD:R_0603_1608Metric | [Farnell] (https://at.farnell.com/yageo/ac0603fr-0710kl/dickschichtwiderstand-10k-1-0/dp/3495224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) | € 0,022 | Min. 10 pcs.
R14 | 10k | Resistor_SMD:R_0603_1608Metric | [Farnell] (https://at.farnell.com/yageo/ac0603fr-0710kl/dickschichtwiderstand-10k-1-0/dp/3495224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) | € 0,022 | Min. 10 pcs.
R15 | 10k | Resistor_SMD:R_0603_1608Metric | [Farnell] (https://at.farnell.com/yageo/ac0603fr-0710kl/dickschichtwiderstand-10k-1-0/dp/3495224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) | € 0,022 | Min. 10 pcs.
R16 | 2.7k | Resistor_SMD:R_0603_1608Metric | [Farnell] (https://at.farnell.com/yageo/ac0603fr-072k7l/dickschichtwiderstand-2k7-1-0/dp/3495256) | € 0,018 | Min. 10 pcs.
R17 | 2.7k | Resistor_SMD:R_0603_1608Metric | [Farnell] (https://at.farnell.com/yageo/ac0603fr-072k7l/dickschichtwiderstand-2k7-1-0/dp/3495256) | € 0,018 | Min. 10 pcs.
R18 | 2.7k | Resistor_SMD:R_0603_1608Metric | [Farnell] (https://at.farnell.com/yageo/ac0603fr-072k7l/dickschichtwiderstand-2k7-1-0/dp/3495256) | € 0,018 | Min. 10 pcs.
R19 | 2.7k | Resistor_SMD:R_0603_1608Metric | [Farnell] (https://at.farnell.com/yageo/ac0603fr-072k7l/dickschichtwiderstand-2k7-1-0/dp/3495256) | € 0,018 | Min. 10 pcs.
R2 | 10k / 0.1% | Resistor_SMD:R_0603_1608Metric | [Farnell] (https://at.farnell.com/panasonic/era3aeb103v/metallsch-widerstand-10k-0-1-0/dp/1577619) | € 0,256 | Min. 10 pcs.
R20 | 0.1 | Resistor_SMD:R_2512_6332Metric | [Farnell] (https://at.farnell.com/yageo/pt2512fk-070r1l/widerstand-aec-q200-0r1-1-1w-2512/dp/3496999?st=pt2512fk) | € 0,488 | Min. 10 pcs.
R21 | 0.1 | Resistor_SMD:R_2512_6332Metric | [Farnell] (https://at.farnell.com/yageo/pt2512fk-070r1l/widerstand-aec-q200-0r1-1-1w-2512/dp/3496999?st=pt2512fk) | € 0,488 | Min. 10 pcs.
R22 | 0.1 | Resistor_SMD:R_2512_6332Metric | [Farnell] (https://at.farnell.com/yageo/pt2512fk-070r1l/widerstand-aec-q200-0r1-1-1w-2512/dp/3496999?st=pt2512fk) | € 0,488 | Min. 10 pcs.
R23 | 0.1 | Resistor_SMD:R_2512_6332Metric | [Farnell] (https://at.farnell.com/yageo/pt2512fk-070r1l/widerstand-aec-q200-0r1-1-1w-2512/dp/3496999?st=pt2512fk) | € 0,488 | Min. 10 pcs.
R24 | 10k | Resistor_SMD:R_0603_1608Metric | [Farnell] (https://at.farnell.com/yageo/ac0603fr-0710kl/dickschichtwiderstand-10k-1-0/dp/3495224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) | € 0,022 | Min. 10 pcs.
R25 | 10k | Resistor_SMD:R_0603_1608Metric | [Farnell] (https://at.farnell.com/yageo/ac0603fr-0710kl/dickschichtwiderstand-10k-1-0/dp/3495224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) | € 0,022 | Min. 10 pcs.
R26 | 10k | Resistor_SMD:R_0603_1608Metric | [Farnell] (https://at.farnell.com/yageo/ac0603fr-0710kl/dickschichtwiderstand-10k-1-0/dp/3495224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) | € 0,022 | Min. 10 pcs.
R27 | 10k | Resistor_SMD:R_0603_1608Metric | [Farnell] (https://at.farnell.com/yageo/ac0603fr-0710kl/dickschichtwiderstand-10k-1-0/dp/3495224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) | € 0,022 | Min. 10 pcs.
R28 | 10k | Resistor_SMD:R_0603_1608Metric | [Farnell] (https://at.farnell.com/yageo/ac0603fr-0710kl/dickschichtwiderstand-10k-1-0/dp/3495224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) | € 0,022 | Min. 10 pcs.
R29 | 10k | Resistor_SMD:R_0603_1608Metric | [Farnell] (https://at.farnell.com/yageo/ac0603fr-0710kl/dickschichtwiderstand-10k-1-0/dp/3495224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) | € 0,022 | Min. 10 pcs.
R3 | 0.1 | Resistor_SMD:R_2512_6332Metric | [Farnell] (https://at.farnell.com/yageo/pt2512fk-070r1l/widerstand-aec-q200-0r1-1-1w-2512/dp/3496999?st=pt2512fk) | € 0,488 | Min. 10 pcs.
R30 | 10k | Resistor_SMD:R_0603_1608Metric | [Farnell] (https://at.farnell.com/yageo/ac0603fr-0710kl/dickschichtwiderstand-10k-1-0/dp/3495224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) | € 0,022 | Min. 10 pcs.
R31 | 10k | Resistor_SMD:R_0603_1608Metric | [Farnell] (https://at.farnell.com/yageo/ac0603fr-0710kl/dickschichtwiderstand-10k-1-0/dp/3495224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) | € 0,022 | Min. 10 pcs.
R32 | 10k | Resistor_SMD:R_0603_1608Metric | [Farnell] (https://at.farnell.com/yageo/ac0603fr-0710kl/dickschichtwiderstand-10k-1-0/dp/3495224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) | € 0,022 | Min. 10 pcs.
R33 | 10k | Resistor_SMD:R_0603_1608Metric | [Farnell] (https://at.farnell.com/yageo/ac0603fr-0710kl/dickschichtwiderstand-10k-1-0/dp/3495224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) | € 0,022 | Min. 10 pcs.
R34 | 10k | Resistor_SMD:R_0603_1608Metric | [Farnell] (https://at.farnell.com/yageo/ac0603fr-0710kl/dickschichtwiderstand-10k-1-0/dp/3495224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) | € 0,022 | Min. 10 pcs. | Alt: [Mouser] (https://www.mouser.at/ProductDetail/Microchip-Technology/MIC24045-EIYFL-TR/?qs=Vt59ZOdFuWaMfRtKJnrPbg%3D%3D) | € 2,050
R35 | 10k | Resistor_SMD:R_0603_1608Metric | [Farnell] (https://at.farnell.com/yageo/ac0603fr-0710kl/dickschichtwiderstand-10k-1-0/dp/3495224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) | € 0,022 | Min. 10 pcs. | Alt: [Mouser] (https://www.mouser.at/ProductDetail/Microchip-Technology/MIC24045-EIYFL-TR/?qs=Vt59ZOdFuWaMfRtKJnrPbg%3D%3D) | € 2,050
R36 | 10k | Resistor_SMD:R_0603_1608Metric | [Farnell] (https://at.farnell.com/yageo/ac0603fr-0710kl/dickschichtwiderstand-10k-1-0/dp/3495224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) | € 0,022 | Min. 10 pcs. | Alt: [Mouser] (https://www.mouser.at/ProductDetail/Microchip-Technology/MIC24045-EIYFL-TR/?qs=Vt59ZOdFuWaMfRtKJnrPbg%3D%3D) | € 2,050
R4 | 0.1 | Resistor_SMD:R_2512_6332Metric | [Farnell] (https://at.farnell.com/yageo/pt2512fk-070r1l/widerstand-aec-q200-0r1-1-1w-2512/dp/3496999?st=pt2512fk) | € 0,488 | Min. 10 pcs. | Alt: [Mouser] (https://www.mouser.at/ProductDetail/Microchip-Technology/MIC24045-EIYFL-TR/?qs=Vt59ZOdFuWaMfRtKJnrPbg%3D%3D) | € 2,050
R5 | 10k | Resistor_SMD:R_0603_1608Metric | [Farnell] (https://at.farnell.com/yageo/ac0603fr-0710kl/dickschichtwiderstand-10k-1-0/dp/3495224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) | € 0,022 | Min. 10 pcs.
R6 | 10k | Resistor_SMD:R_0603_1608Metric | [Farnell] (https://at.farnell.com/yageo/ac0603fr-0710kl/dickschichtwiderstand-10k-1-0/dp/3495224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) | € 0,022 | Min. 10 pcs.
R7 | 10k | Resistor_SMD:R_0603_1608Metric | [Farnell] (https://at.farnell.com/yageo/ac0603fr-0710kl/dickschichtwiderstand-10k-1-0/dp/3495224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) | € 0,022 | Min. 10 pcs.
R8 | 10k | Resistor_SMD:R_0603_1608Metric | [Farnell] (https://at.farnell.com/yageo/ac0603fr-0710kl/dickschichtwiderstand-10k-1-0/dp/3495224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) | € 0,022 | Min. 10 pcs.
R9 | 10k | Resistor_SMD:R_0603_1608Metric | [Farnell] (https://at.farnell.com/yageo/ac0603fr-0710kl/dickschichtwiderstand-10k-1-0/dp/3495224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) | € 0,022 | Min. 10 pcs.
U1 | ADS1115IDGS | Package_SO:TSSOP-10_3x3mm_P0.5mm | [Farnell] (https://at.farnell.com/texas-instruments/ads1115idgsr/adc-16bit-860sps-i2c-vssop-10/dp/3116562?st=ads1115idgs) | € 5,150 | - | Alt: [Mouser] (https://www.mouser.at/ProductDetail/Texas-Instruments/PCA9548APWR/?qs=dB0LedT%252BmmAWc5k7y2UrXA%3D%3D) | € 2,310
U10 | INA219 | Package_TO_SOT_SMD:SOT-23-8 | [Farnell] (https://at.farnell.com/texas-instruments/ina219aidcnr/current-power-monitor-120db-8sot23/dp/3118164?st=ina219) | € 2,340 | -
U11 | INA219 | Package_TO_SOT_SMD:SOT-23-8 | [Farnell] (https://at.farnell.com/texas-instruments/ina219aidcnr/current-power-monitor-120db-8sot23/dp/3118164?st=ina219) | € 2,340 | -
U12 | INA219 | Package_TO_SOT_SMD:SOT-23-8 | [Farnell] (https://at.farnell.com/texas-instruments/ina219aidcnr/current-power-monitor-120db-8sot23/dp/3118164?st=ina219) | € 2,340 | -
U2 | INA219 | Package_TO_SOT_SMD:SOT-23-8 | [Farnell] (https://at.farnell.com/texas-instruments/ina219aidcnr/current-power-monitor-120db-8sot23/dp/3118164?st=ina219) | € 2,340 | -
U3 | INA219 | Package_TO_SOT_SMD:SOT-23-8 | [Farnell] (https://at.farnell.com/texas-instruments/ina219aidcnr/current-power-monitor-120db-8sot23/dp/3118164?st=ina219) | € 2,340 | -
U4 | TCA9548APW | Package_SO:TSSOP-24_4.4x7.8mm_P0.65mm | [Farnell] (https://at.farnell.com/nxp/pca9548apw-118/i2c-bus-switch-8-kan-le-5-5v-tssop/dp/2841042) | € 1,460 | -
U5 | MIC24045 | myfootprint:FQFN33-20LD-PL-1 | [Farnell] (https://at.farnell.com/microchip/mic24045-2zyfl-tr/dc-dc-wandler-sync-buck-310khz/dp/2667213?st=mic24045) | € 1,830 | -
U6 | MIC24045 | myfootprint:FQFN33-20LD-PL-1 | [Farnell] (https://at.farnell.com/microchip/mic24045-2zyfl-tr/dc-dc-wandler-sync-buck-310khz/dp/2667213?st=mic24045) | € 1,830 | -
U7 | MIC24045 | myfootprint:FQFN33-20LD-PL-1 | [Farnell] (https://at.farnell.com/microchip/mic24045-2zyfl-tr/dc-dc-wandler-sync-buck-310khz/dp/2667213?st=mic24045) | € 1,830 | -
U8 | MIC24045 | myfootprint:FQFN33-20LD-PL-1 | [Farnell] (https://at.farnell.com/microchip/mic24045-2zyfl-tr/dc-dc-wandler-sync-buck-310khz/dp/2667213?st=mic24045) | € 1,830 | -
U9 | INA219 | Package_TO_SOT_SMD:SOT-23-8 | [Farnell] (https://at.farnell.com/texas-instruments/ina219aidcnr/current-power-monitor-120db-8sot23/dp/3118164?st=ina219) | € 2,340 | -
 |  |  | Σ | € 57,127

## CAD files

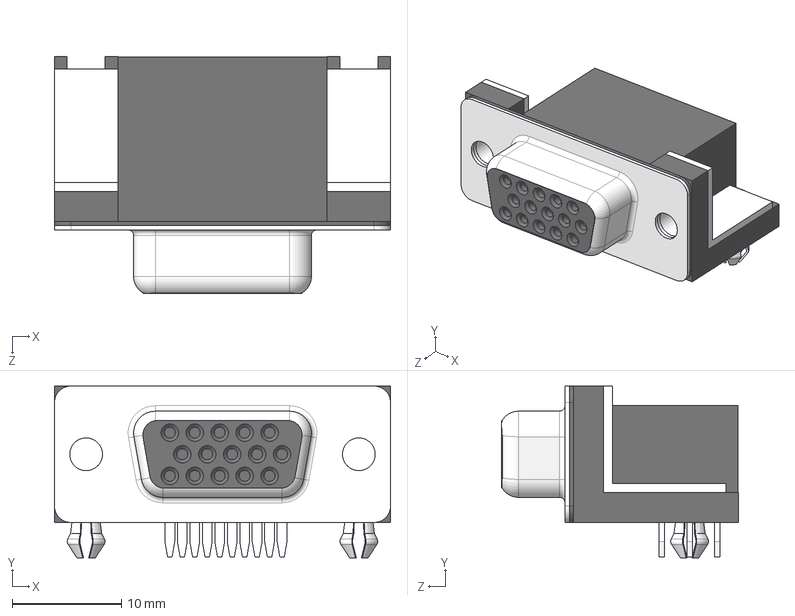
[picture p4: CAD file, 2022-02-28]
kicad/3dshapes/L77HDE15SD1CH4RHNVGA.stp
30.8 x 15.8 x 21.7 mm

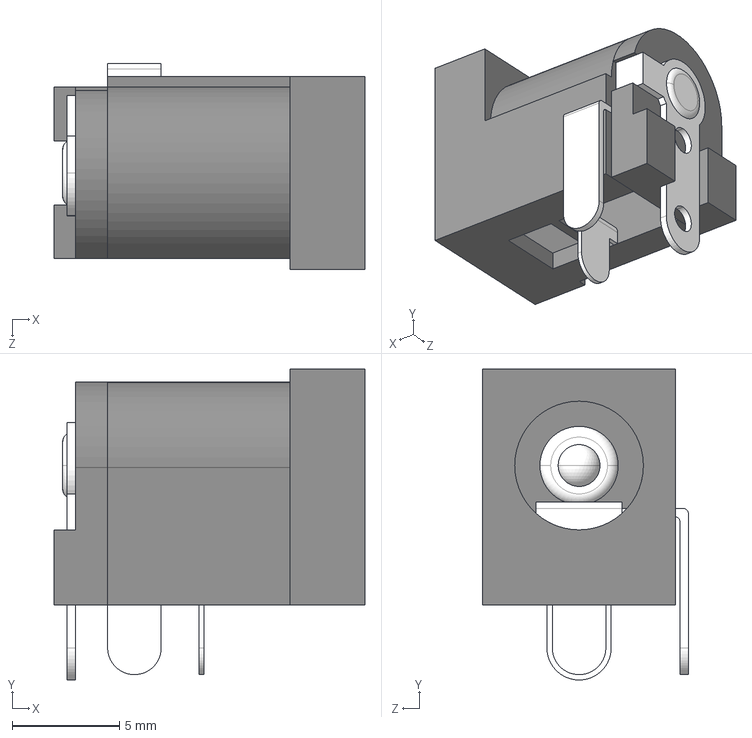
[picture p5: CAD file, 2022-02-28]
kicad/3dshapes/MJ-179PH.stp
14.5 x 14.5 x 9.60 mm

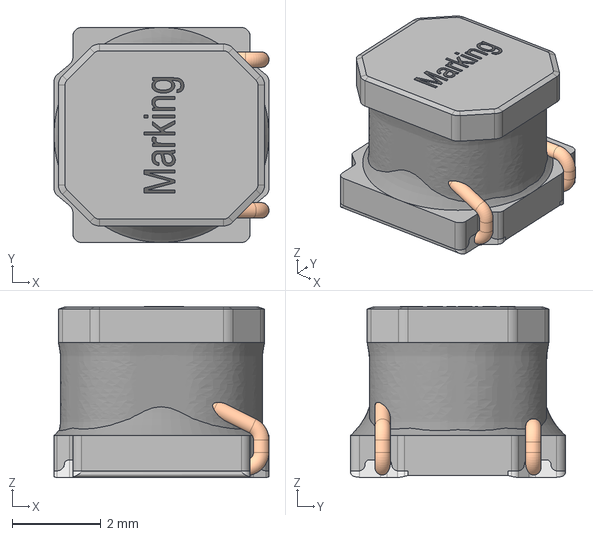
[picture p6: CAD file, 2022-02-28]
kicad/3dshapes/SRN5040TA-1R0M.stp
4.85 x 4.85 x 3.86 mm

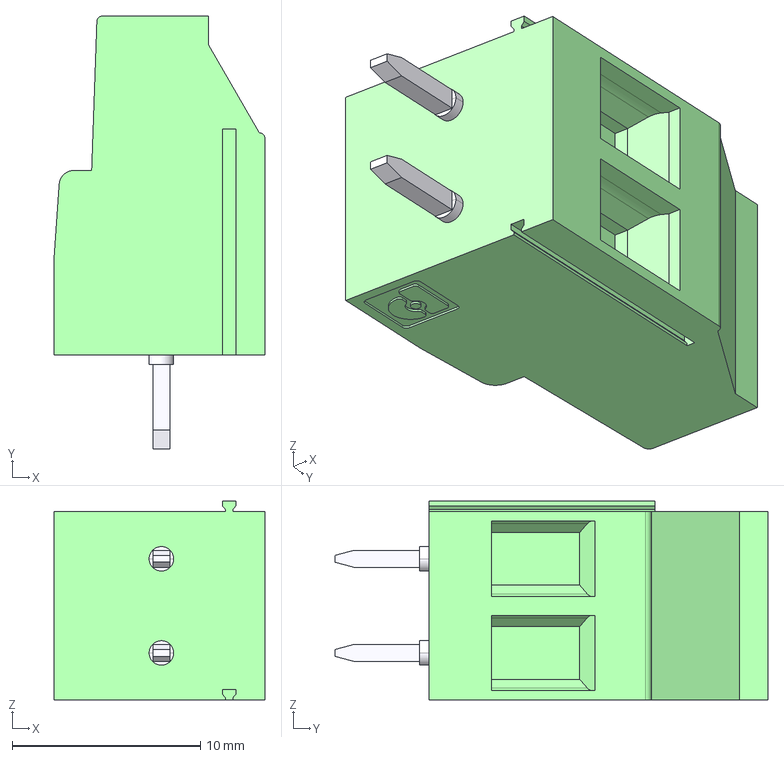
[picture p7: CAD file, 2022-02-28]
kicad/3dshapes/1711026.stp
11.2 x 23.0 x 10.6 mm

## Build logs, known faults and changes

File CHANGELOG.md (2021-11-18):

# Changelog
All notable changes to this project will be documented in this file.

The format is based on [Keep a Changelog](https://keepachangelog.com/en/1.0.0/), and this project adheres to [Semantic Versioning](https://semver.org/spec/v2.0.0.html).
However, the major and minor number are used to express the version of the hardware platform while the patch version expresses additional revision of software modules only.

## [dev]
### Added
### Changed
### Removed

## [1.0] - 2021-03-23
### Added
- First design of the ETB
- Initial software library
- First example scripts

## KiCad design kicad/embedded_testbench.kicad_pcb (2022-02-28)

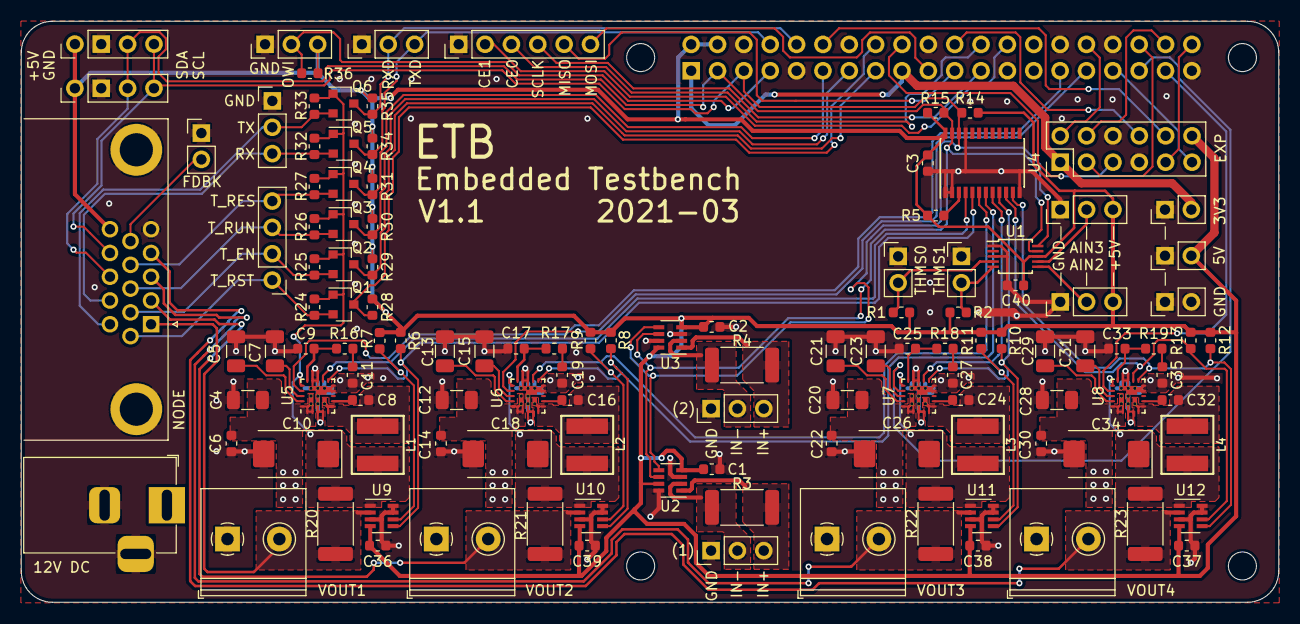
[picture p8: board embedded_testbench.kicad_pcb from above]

Board: 2 copper layers, 121.2 x 56.0 mm, 127 parts (1 on the bottom side), 86 nets.

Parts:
C1, C2, C3, C6, C8, C14, C16, C22, C24, C30, C32, C36, C37, C38, C39, C40: 100n; C_0603_1608Metric
C4, C12, C20, C28: 22u; C_1206_3216Metric
C5, C7, C13, C15, C21, C23, C29, C31: 2.2u; C_1206_3216Metric
C9, C17, C25, C33: 47p; C_0603_1608Metric
C10, C18, C26, C34: 100u; CP_EIA-7343-31_Kemet-D
C11, C19, C27, C35: 10n; C_0603_1608Metric
J1: 12V INPUT; BarrelJack_Horizontal
J2: THMS1; PinHeader_1x02_P2.54mm_Vertical
J3: THMS2; PinHeader_1x02_P2.54mm_Vertical
J4: VOUT1; TerminalBlock_Philmore_TB132_1x02_P5.00mm_Horizontal
J5: UARTS; PinHeader_1x03_P2.54mm_Vertical
J6: CTRLS; PinHeader_1x04_P2.54mm_Vertical
J7: VOUT2; TerminalBlock_Philmore_TB132_1x02_P5.00mm_Horizontal
J8: VOUT3; TerminalBlock_Philmore_TB132_1x02_P5.00mm_Horizontal
J9: PM1; PinHeader_1x03_P2.54mm_Vertical
J10: VOUT4; TerminalBlock_Philmore_TB132_1x02_P5.00mm_Horizontal
J11: PM2; PinHeader_1x03_P2.54mm_Vertical
J12: SPI; PinHeader_1x06_P2.54mm_Vertical
J13: 5V; PinHeader_1x02_P2.54mm_Vertical
J14: 3V3; PinHeader_1x02_P2.54mm_Vertical
J15: GND; PinHeader_1x02_P2.54mm_Vertical
J16: UART; PinHeader_1x03_P2.54mm_Vertical
J17: OWI; PinHeader_1x03_P2.54mm_Vertical
J18: AIN2; PinHeader_1x03_P2.54mm_Vertical
J19: AIN3; PinHeader_1x03_P2.54mm_Vertical
J20: TWI1; PinHeader_1x04_P2.54mm_Vertical
J21: TWI2; PinHeader_1x04_P2.54mm_Vertical
J22: FDBK; PinHeader_1x02_P2.54mm_Vertical
J23: EXP; PinHeader_2x06_P2.54mm_Vertical
J24: WSN_NODE; DSUB-15-HD_Female_Horizontal_P2.29x1.98mm_EdgePinOffset8.35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
L1, L2, L3, L4: 2.2u; L_Bourns-SRN5040
MK1, MK2, MK3, MK4: M2.5; MountingHole_2.7mm_M2.5
P1: RPi Header; PinSocket_2x20_P2.54mm_Vertical
Q1, Q2, Q3, Q4, Q5, Q6: BSS138; SOT-23
R1, R2: 10k (0.1%); R_0603_1608Metric
R3, R4, R20, R21, R22, R23: 0.1; R_2512_6332Metric
R5, R6, R7, R8, R9, R10, R11, R12, R13, R14, R15, R24, R25, R26, R27, R28, R29, R30, R31, R32, R33, R34, R35, R36: 10k; R_0603_1608Metric
R16, R17, R18, R19: 2.7k; R_0603_1608Metric
U1: ADS1115IDGS; TSSOP-10_3x3mm_P0.5mm
U2, U3, U9, U10, U11, U12: INA219; SOT-23-8
U4: TCA9548APW; TSSOP-24_4.4x7.8mm_P0.65mm
U5, U6, U7, U8: MIC24045; FQFN33-20LD-PL-1

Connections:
+3V3: J14.2, J23.1, P1.1, P1.17
+5V: C1.1, C2.1, C3.1, C36.1, C37.1, C38.1, C39.1, C40.2, J13.2, J17.3, J18.3, J19.3, J20.1, J21.1, J23.12, J24.15, P1.2, P1.4, R1.1, R2.1, R5.2, R6.1, R7.1, R8.1, R9.1, R10.1, R11.1, R12.1, R13.1, R14.1, R15.1, R28.1, R29.1, R30.1, R31.1, R34.1, R35.1, R36.1, U1.8, U2.4, U2.7, U3.4, U3.8, U4.24, U9.4, U10.4, U11.4, U12.4
+12V: C4.1, C6.1, C12.1, C14.1, C20.1, C22.1, C28.1, C30.1, J1.1, U5.1, U5.2, U5.20, U5.21, U6.1, U6.2, U6.20, U6.21, U7.1, U7.2, U7.20, U7.21, U8.1, U8.2, U8.20, U8.21
/AIN0: J2.2, R1.2, U1.4
/AIN1: J3.2, R2.2, U1.5
/AIN2: J18.2, U1.6
/AIN3: J19.2, U1.7
/EN1: P1.29, U5.17
/EN2: P1.31, U6.17
/EN3: P1.35, U7.17
/EN4: P1.37, U8.17
/ENS: J6.2, J24.7, Q2.2, R25.2
/FDBK: J22.2, J24.10
/GPIO16: J23.3, P1.36
/GPIO18: J23.10, P1.12
/GPIO20: J23.4, P1.38
/GPIO21: J23.9, P1.40
/GPIO24: J23.5, P1.18
/GPIO25: J23.8, P1.22
/OWI: J17.2, P1.7, R36.2
/PWM0: J23.2, P1.32
/PWM1: J23.11, P1.33
/RESS: J6.4, J24.9, Q4.2, R27.2
/RSTS: J6.1, J24.6, Q1.2, R24.2
/RUNS: J6.3, J24.8, Q3.2, R26.2
/RXD: J16.2, P1.10, Q6.3, R35.2
/RXS: J5.3, J24.12, Q5.2, R32.2
/SC1: R6.2, U4.5, U5.11, U9.5
/SC2: R8.2, U4.7, U6.11, U10.5
/SC3: R10.2, U4.9, U7.11, U11.5
/SC4: R12.2, U4.11, U8.11, U12.5
/SCL: J20.4, J21.4, J24.14, P1.5, R14.2, U1.10, U2.5, U3.5, U4.22
/SD1: R7.2, U4.4, U5.12, U9.6
/SD2: R9.2, U4.6, U6.12, U10.6
/SD3: R11.2, U4.8, U7.12, U11.6
/SD4: R13.2, U4.10, U8.12, U12.6
/SDA: J20.3, J21.3, J24.13, P1.3, R15.2, U1.9, U2.6, U3.6, U4.23
/SPI_CE0: J12.3, P1.24
/SPI_CE1: J12.2, P1.26
/SPI_MISO: J12.5, P1.21
/SPI_MOSI: J12.6, P1.19
/SPI_SCLK: J12.4, P1.23
/TXD: J16.3, P1.8, Q5.3, R34.2
/TXS: J5.2, J24.11, Q6.2, R33.2
/T_EN: P1.15, Q2.3, R29.2
/T_RES: P1.11, Q4.3, R31.2
/T_RST: P1.16, Q1.3, R28.2
/T_RUN: P1.13, Q3.3, R30.2
/VIN_A1+: J9.3, R3.1, U2.1
/VIN_A1-: J9.2, R3.2, U2.2
/VIN_A2+: J11.3, R4.1, U3.1
/VIN_A2-: J11.2, R4.2, U3.2
/VO1: J4.2, J24.1, R20.2, U9.2
/VO2: J7.2, J24.2, R21.2, U10.2
/VO3: J8.2, J24.3, R22.2, U11.2
/VO4: J10.2, J24.4, R23.2, U12.2
/VOUT1: C10.1, L1.2, Q1.1, Q2.1, Q3.1, Q4.1, Q5.1, Q6.1, R20.1, R24.1, R25.1, R26.1, R27.1, R32.1, R33.1, U5.16, U9.1
/VOUT2: C18.1, L2.2, R21.1, U6.16, U10.1
/VOUT3: C26.1, L3.2, R22.1, U7.16, U11.1
/VOUT4: C34.1, L4.2, R23.1, U8.16, U12.1
GND: C1.2, C2.2, C3.2, C4.2, C5.2, C6.2, C7.1, C9.1, C10.2, C11.1, C12.2, C13.2, C14.2, C15.1, C17.1, C18.2, C19.1, C20.2, C21.2, C22.2, C23.1, C25.1, C26.2, C27.1, C28.2, C29.2, C30.2, C31.1, C33.1, C34.2, C35.1, C36.2, C37.2, C38.2, C39.2, C40.1, J1.2, J1.3, J2.1, J3.1, J4.1, J5.1, J7.1, J8.1, J9.1, J10.1, J11.1, J12.1, J13.1, J14.1, J15.1, J15.2, J16.1, J17.1, J18.1, J19.1, J20.2, J21.2, J22.1, J23.6, J23.7, J24.0, J24.5, P1.6, P1.9, P1.14, P1.20, P1.25, P1.30, P1.34, P1.39, U1.1, U1.3, U2.3, U2.8, U3.3, U3.7, U4.1, U4.2, U4.12, U4.21, U5.3, U5.4, U5.9, U5.10, U5.13, U5.14, U5.22, U6.3, U6.4, U6.9, U6.10, U6.13, U6.14, U6.22, U7.3, U7.4, U7.9, U7.10, U7.13, U7.14, U7.22, U8.3, U8.4, U8.9, U8.10, U8.13, U8.14, U8.22, U9.3, U9.7, U9.8, U10.3, U10.7, U10.8, U11.3, U11.7, U11.8, U12.3, U12.7, U12.8
unnamed: C5.1, U5.19
unnamed: C7.2, U5.18
unnamed: C8.1, U5.7
unnamed: C8.2, L1.1, U5.5, U5.6, U5.23
unnamed: C9.2, R16.2, U5.15
unnamed: C11.2, R16.1
unnamed: C13.1, U6.19
unnamed: C15.2, U6.18
unnamed: C16.1, U6.7
unnamed: C16.2, L2.1, U6.5, U6.6, U6.23
unnamed: C17.2, R17.2, U6.15
unnamed: C19.2, R17.1
unnamed: C21.1, U7.19
unnamed: C23.2, U7.18
unnamed: C24.1, U7.7
unnamed: C24.2, L3.1, U7.5, U7.6, U7.23
unnamed: C25.2, R18.2, U7.15
unnamed: C27.2, R18.1
unnamed: C29.1, U8.19
unnamed: C31.2, U8.18
unnamed: C32.1, U8.7
unnamed: C32.2, L4.1, U8.5, U8.6, U8.23
unnamed: C33.2, R19.2, U8.15
unnamed: C35.2, R19.1
unnamed: R5.1, U4.3

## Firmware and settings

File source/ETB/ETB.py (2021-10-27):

#####
# @brief   Embedded Testbench (ETB) module
#
# Module containing the embedded testbench (ETB) class.
#
# @file     /etb/ETB.py
# @author   $Author: Dominik Widhalm $
# @version  $Revision: 1.0 $
# @date     $Date: 2021/04/30 $
#
# @note     Don't forget to enable I2C, e.g. with sudo raspi-config
#
# @example  For examples refer to the scripts in the examples directory
#####


##### LIBRARIES #####
### GLOBAL ###
# time (for sleep method)
import time
# GPIO functionality (imported as GPIO)
import RPi.GPIO as GPIO
# for GPIO numbering, choose BCM mode
GPIO.setmode(GPIO.BCM)
# Disable GPIO in-use warnings
GPIO.setwarnings(False)

### ETB ###
# Core functionality
from ETB.core.INA219 import *
from ETB.core.VSM import *
from ETB.core.ADS1115 import *
# Misc
from ETB.sens.JT103 import raw_to_degree


##### GLOBAL VARIABLES #####
# Test control signals
T_RST_GPIO = 23
T_EN_GPIO  = 22
T_RUN_GPIO = 27
T_RES_GPIO = 17


#####
# @class    ETB
# @brief    ETB embedded testbench
#
# Class for the VSM voltage scaling module used on the ETB.
#####
class ETB(object):
    ###
    # The constructor.
    #
    # @param[in]    self            The object pointer.
    ###
    def __init__(self):
        # @var _vsm
        # voltage scaling module (with default enable lines)
        self._vsm = VSM()
        # @var _adc
        # onboard ADC (with default I2C address)
        self._adc = ADS1115()
        # @var _inaaux[]
        # auxiliary INA wattmeters
        self._inaaux = [None]*3
        self._inaaux[1] = INA219(0x41)
        self._inaaux[2] = INA219(0x44)
        # Calibrate the INA
        for i in range(1,3):
            # Check if MIC is really enabled
            self._inaaux[i].calibrate()
        # @var __t_rst
        # Object's GPIO pin (BCM) for T_RST (active low)
        self.__trst = T_RST_GPIO
        GPIO.setup(self.__trst, GPIO.OUT)
        GPIO.output(self.__trst, GPIO.HIGH)
        # @var __t_en
        # Object's GPIO pin (BCM) for T_EN
        self.__ten = T_EN_GPIO
        GPIO.setup(self.__ten, GPIO.OUT)
        GPIO.output(self.__ten, GPIO.LOW)
        # @var __t_run
        # Object's GPIO pin (BCM) for T_RUN
        self.__trun = T_RUN_GPIO
        GPIO.setup(self.__trun, GPIO.IN)
        # @var __t_res
        # Object's GPIO pin (BCM) for T_RES
        self.__tres = T_RES_GPIO
        GPIO.setup(self.__tres, GPIO.IN)


    ###
    # Check if a given output channel is enabled.
    #
    # @param[in]    self            The object pointer.
    # @param[in]    channel         Channel to be selected (1-4)
    # @return       True if enabled; False otherwise
    ###
    def ch_is_enabled(self, channel):
        return self._vsm.ch_is_enabled(channel)


    ###
    # Enable a given output channel (1-4).
    #
    # @param[in]    self            The object pointer.
    # @param[in]    channel         Channel to be selected (1-4)
    # @return       True is enabled; False otherwise
    ###
    def ch_enable(self, channel):
        return self._vsm.ch_enable(channel)


    ###
    # Disable a given output channel (1-4).
    #
    # @param[in]    self            The object pointer.
    # @param[in]    channel         Channel to be selected (1-4)
    # @return       True is enabled; False otherwise
    ###
    def ch_disable(self, channel):
        return self._vsm.ch_disable(channel)


    # Enable all output channels.
    #
    # @param[in]    self            The object pointer.
    # @return       True is enabled; False otherwise
    ###
    def ch_enable_all(self):
        return self._vsm.ch_enable_all()


    ###
    # Disable all output channels.
    #
    # @param[in]    self            The object pointer.
    # @return       True is enabled; False otherwise
    ###
    def ch_disable_all(self):
        return self._vsm.ch_disable_all()


    ###
    # Set the current limit of a given output channel (1-4).
    #
    # @param[in]    self            The object pointer.
    # @param[in]    channel         Channel to be selected (1-4)
    # @param[in]    ilim            Current limit for the MIC (default: 2A)
    # @return       True in case of success; False otherwise
    ###
    def ch_limit_A(self, channel, ilim=2):
        return self._vsm.ch_limit_A(channel, ilim)


    ###
    # Set the current limit of all output channels.
    #
    # @param[in]    self            The object pointer.
    # @param[in]    ilim            Current limit for the MIC (default: 2A)
    # @return       True in case of success; False otherwise
    ###
    def ch_limit_A_all(self, ilim=2):
        return self._vsm.ch_limit_A_all(ilim)


    ###
    # Calibrate a given output channel (1-4).
    #
    # @param[in]    self            The object pointer.
    # @param[in]    channel         Channel to be selected (1-4)
    # @param[in]    imax            Maximum current for the INA (default: 400mA)
    # @return       True in case of success; False otherwise
    ###
    def ch_calibrate_A(self, channel, imax=INA219_CAL_400MA):
        return self._vsm.ch_calibrate_A(channel, imax)


    ###
    # Calibrate all output channels.
    #
    # @param[in]    self            The object pointer.
    # @param[in]    imax            Maximum current for the INA (default: 400mA)
    # @return       True in case of success; False otherwise
    ###
    def ch_calibrate_A_all(self, imax=INA219_CAL_400MA):
        return self._vsm.ch_calibrate_A_all(imax)


    ###
    # Set the Vout value of a given output channel (1-4).
    #
    # @param[in]    self            The object pointer.
    # @param[in]    channel         Channel to be selected (1-4)
    # @param[in]    value           Decimal value of the vout register
    # @return       True in case of success; False otherwise
    ###
    def ch_set_V_decimal(self, channel, value):
        return self._vsm.ch_set_V_decimal(channel, value)


    ###
    # Set the Vout value of all output channels.
    #
    # @param[in]    self            The object pointer.
    # @param[in]    value           Decimal value of the vout register
    # @return       True in case of success; False otherwise
    ###
    def ch_set_V_decimal_all(self, value):
        return self._vsm.ch_set_V_decimal_all(value)


    ###
    # Set the output voltage (V) of a given output channel (1-4).
    #
    # @param[in]    self            The object pointer.
    # @param[in]    channel         Channel to be selected (1-4)
    # @param[in]    volt            Output voltage in volts (V)
    # @return       True in case of success; False otherwise
    ###
    def ch_set_V(self, channel, volt):
        return self._vsm.ch_set_V(channel, volt)


    ###
    # Set the output voltage (V) of all output channels.
    #
    # @param[in]    self            The object pointer.
    # @param[in]    volt            Output voltage in volts (V)
    # @return       True in case of success; False otherwise
    ###
    def ch_set_V_all(self, volt):
        return self._vsm.ch_set_V_all(volt)
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

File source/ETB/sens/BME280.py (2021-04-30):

#####
# @brief   BME280 environmental sensor
#
# Module containing the BME280 environmental sensor class.
#
# @file     /etb/sens/BME280.py
# @author   $Author: Dominik Widhalm $
# @version  $Revision: 1.0 $
# @date     $Date: 2021/04/02 $
#
# @note     Don't forget to enable I2C, e.g. with sudo raspi-config
# @see      https://github.com/adafruit/Adafruit_Python_BME280/
# @see      https://github.com/rm-hull/bme280
#
# @example  bme = BME280()                # Get an instance with default I2C address (0x76)
# @example  temp = bme.read_temperature() # Read the current temperature [°C]
# @example  pres = bme.read_pressure()    # Read the current pressure [hPa]
# @example  humi = bme.read_humidity()    # Read the current relative humidity [%]
# @example  dewp = bme.read_dewpoint()    # Calculate the dewpoint [°C]
#####


##### LIBRARIES #####
# smbus (provides subset of I2C functionality)
import smbus
# time (for sleep method)
import time


##### GLOBAL VARIABLES #####
# Register addresses
BME280_REG_CHIPID       = 0xD0
BME280_REG_RESET        = 0xE0
BME280_REG_CTRL_HUM     = 0xF2
BME280_REG_STATUS       = 0xF3
BME280_REG_CTRL_MEAS    = 0xF4
BME280_REG_CONFIG       = 0xF5
BME280_REG_P_MSB        = 0xF7
BME280_REG_P_LSB        = 0xF8
BME280_REG_P_XLSB       = 0xF9
BME280_REG_T_MSB        = 0xFA
BME280_REG_T_LSB        = 0xFB
BME280_REG_T_XLSB       = 0xFC
BME280_REG_H_MSB        = 0xFD
BME280_REG_H_LSB        = 0xFE
### Compensation Registers ###
# Temperature compensation registers
BME280_REG_DIG_T1       = 0x88  # unsigned short
BME280_REG_DIG_T2       = 0x8A  # signed short
BME280_REG_DIG_T3       = 0x8C  # signed short
# Pressure compensation registers
BME280_REG_DIG_P1       = 0x8E  # unsigned short
BME280_REG_DIG_P2       = 0x90  # signed short
BME280_REG_DIG_P3       = 0x92  # signed short
BME280_REG_DIG_P4       = 0x94  # signed short
BME280_REG_DIG_P5       = 0x96  # signed short
BME280_REG_DIG_P6       = 0x98  # signed short
BME280_REG_DIG_P7       = 0x9A  # signed short
BME280_REG_DIG_P8       = 0x9C  # signed short
BME280_REG_DIG_P9       = 0x9E  # signed short
# Humidity compensation registers
BME280_REG_DIG_H1       = 0xA1  # unsigned short
BME280_REG_DIG_H2       = 0xE1  # signed short
BME280_REG_DIG_H3       = 0xE3  # unsigned short
BME280_REG_DIG_H4       = 0xE4  # signed short
BME280_REG_DIG_H5       = 0xE5  # signed short
BME280_REG_DIG_H6       = 0xE6  # signed short
BME280_REG_DIG_H7       = 0xE7  # signed short
### Settings ###
# Oversampling of data (osrs_X)
BME280_OSRS_T_OFFSET    = 5
BME280_OSRS_T_MASK      = 0x1F
BME280_OSRS_P_OFFSET    = 2
BME280_OSRS_P_MASK      = 0xE3
BME280_OSRS_H_OFFSET    = 0
BME280_OSRS_H_MASK      = 0xF8
BME280_OSRS = {
    0:      0x00,
    1:      0x01,
    2:      0x02,
    4:      0x03,
    8:      0x04,
    16:     0x05,
}
# Sensor mode (mode)
BME280_MODE_OFFSET      = 0
BME280_MODE_MASK        = 0xFC
BME280_MODE_SLEEP       = 0
BME280_MODE_FORCED      = 1
BME280_MODE_NORMAL      = 3
# Standby-time in normal mode (t_sb)
BME280_T_SB_OFFSET      = 5
BME280_T_SB_MASK        = 0x1F
BME280_T_SB = {
    0.5:    0x00,
    62.5:   0x01,
    125:    0x02,
    250:    0x03,
    500:    0x04,
    1000:   0x05,
    10:     0x06,
    20:     0x07
}
# Time constant of the IIR filter (filter)
BME280_FILTER_OFFSET    = 2
BME280_FILTER_MASK      = 0xE3
BME280_FILTER = {
    0:      0x00,
    2:      0x01,
    4:      0x02,
    8:      0x03,
    16:     0x04
}

# 3-wire SPI interface enable (spi3w_en)
BME280_SPI2W_EN_OFFSET  = 0
BME280_SPI2W_EN_MASK    = 0xFE
BME280_SPI2W_EN_OFF     = 0
BME280_SPI2W_EN_ON      = 1
### RESET ###
BME280_RESET_VALUE      = 0xB6


#####
# @class    BME280
# @brief    BME280 environmental sensor
#
# Class for the BME280 environmental sensor.
class BME280(object):
    ###
    # The constructor.
    #
    # @param[in]    self        The object pointer.
    # @param[in]    address     Specific I2C address (default: 0x76)
    # @param[in]    busnum      Specific I2C bus number (default: 1)
    def __init__(self, address=0x76, busnum=1):
        # @var __i2c_address
        # Object's own I2C address
        self.__i2c_address = address
        # @var __bus
        # Object's own I2C bus number
        self.__bus = smbus.SMBus(busnum)
        # @var __t_fine
        # Object's own fine resolution temperature value (initially 0.0)
        self.__t_fine = 0.0

        # Load calibration values
        self._load_calibration()
        #  Disable SPI interface
        self.spi_disable()
        # Set the temperature sampling mode
        self.set_t_sample(1)
        # Set the pressure sampling mode
        self.set_p_sample(1)
        # Set the humidity sampling mode
        self.set_h_sample(1)
        # Set the standby mode
        self.set_standby(250)
        # Set the filer mode
        self.set_filter(0)
        # Set the mode of operation
        self.set_mode(BME280_MODE_NORMAL)


    ###
    # Write a byte (8-bit) to the specified I2C register.
    #
    # @param[in]    self            The object pointer.
    # @param[in]    register        The I2C register address.
    # @param[in]    value           The byte value to be written.
    # @return       True in case of success; otherwise False.
    def _i2c_write_8(self, register, value):
        # Write the given value to the specified register
        return self.__bus.write_byte_data(self.__i2c_address, register, (value&0xFF))


    ###
    # Read an unsigned byte (8-bit) from the specified I2C register.
    #
    # @param[in]    self            The object pointer.
    # @param[in]    register        The I2C register address.
    # @return       True in case of success; otherwise False.
    def _i2c_read_U8(self, register):
        # Read value from the specified register
        return (self.__bus.read_byte_data(self.__i2c_address, register) & 0xFF)


    ###
    # Read a signed byte (8-bit) from the specified I2C register.
    #
    # @param[in]    self            The object pointer.
    # @param[in]    register        The I2C register address.
    # @return       Signed byte value in case of success; otherwise False.
    def _i2c_read_S8(self, register):
        # First, read value as unsigned byte
        result = self._i2c_read_U8(register)
        # Check return value
        if result is False:
            return False
        # Check for sign bit and turn into a negative value if set.
        if result & 0x80 != 0:
            result -= 1 << 8
        return result
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

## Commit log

2021-03-23 Added kicad files of ETB v1.0 (incl. own symbols/footprints)
    [embedded_testbench.kicad_pcb, embedded_testbench.ods, embedded_testbench.sch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]
2021-03-23 Added renderedimage of ETB v1.0 PCB (front/back)
2021-03-23 Added gitignore for kicad projects
2021-03-24 Added PCB design documentation
2021-03-24 Updated PCB design docu and added schematics
2021-03-24 Croped schematics and added white background
2021-03-24 Reworked PCB design documentation (table instead of list) Resized PCB board images
2021-03-24 Minor format fix for PCB design documentation
2021-03-24 Minor fix in PCB board (back) image
2021-03-24 Corrected R values in PCB design documentation
2021-04-01 Reworked core modules to use parameter lists (for value checks)
    [INA219.py, MIC24045.py]
2021-04-01 Added VSM core module (replaces previous ExpSetup)
    [VSM.py]
2021-04-01 Enhanced core INA219 calibration
2021-04-02 Minor fixed to ETB/core modules
    [MIC24045.py, VSM.py]
2021-04-02 Reworked and added BME280 sensor module
    [BME280.py]
2021-04-02 Minor format fix in ETB/sens/BME280 module
    [BME280.py]
2021-04-02 Fixed capitalization of variable names in ETB/sens/BME280 module
    [BME280.py]
2021-04-08 Corrected ETB core file access rights
    [ADS1115.py, INA219.py, MIC24045.py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]
2021-04-08 Added reworkd sensor modules (BME280, DS18B20, LM75; stemma was removed)
    [BME280.py, DS18B20.py, LM75.py]
2021-04-08 Removed legacy sensor modules
2021-04-08 Added sensor datasheets
2021-04-08 Added JT thermistor datasheet
2021-04-08 Added JT103 thermistor module
2021-04-14 Added interactive HTML BOM
2021-04-14 Updated schematic, PCB, and BOM (fixed part values and Farnell links)
    [embedded_testbench.kicad_pcb, embedded_testbench.ods, embedded_testbench.sch]
2021-04-20 Fixed wrong link of 12V DC jack in BOM
    [embedded_testbench.ods]
2021-04-20 Fixed major PCB issue: wrongly connected 12V DC barrel jack
    [embedded_testbench.kicad_pcb, embedded_testbench.sch]
2021-04-20 First bugfixes after trying on real hardware
    [ADS1115.py, BME280.py, ETB.py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]
2021-04-20 Fixed more bugs and added more module tests for ETB
    [ADS1115.py, ETB.py, INA219.py]
2021-04-20 Updated PCB design
    Updated silk layer labels
    Some minor improvements
    [embedded_testbench.kicad_pcb, embedded_testbench.sch]
2021-04-21 Bug fixes and improvements for Python library
    Fixed function return values (is not != is False)
    Fixed function headers (doxygen)
    Improved general code quality
    [ADS1115.py, BME280.py, DS18B20.py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]
2021-04-21 Fixed ADS1115 library (wrong register address)
    [ADS1115.py, ETB.py, JT103.py]
2021-04-21 More fixes to PCB silk layer
    [embedded_testbench.kicad_pcb]
2021-04-30 Added supply voltage sweep example script
2021-04-30 Added power monitor example script
2021-04-30 Added supply voltage sweep example with result plotting script
2021-04-30 Added ETB self-check example script Fixed some small bugs LM75 suddenly reports wrong value; needs to be checked
    [BME280.py, ETB.py, JT103.py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]
2021-08-11 Updated ETB PCB images
2021-08-11 Added missing libraries to voltage sweet demos
2021-09-29 Started implementing SHTC3 library (not working yet because of 16-bit register addresses)
    [SHTC3.py]
2021-10-06 Fixed incorrect (absolute) path for kicad symbol library (need to find a relative solution)
2022-02-04 Updated PCB plots (incl. 3D view)
2022-02-28 Added missing 3d models and updated figures
    [1711026.stp, L77HDE15SD1CH4RHNVGA.stp, MJ-179PH.stp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]
2022-02-28 Remoded unintended artefacts from PCB figures
